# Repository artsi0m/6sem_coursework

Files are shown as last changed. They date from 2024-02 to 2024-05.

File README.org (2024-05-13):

* Курсовой шестого семестра
Программное обеспечение моделирования физических процессов,
протекающих в системе тестирования сервоприводов квадрокоптера на микроконтроллере ATmega328P

** Используемые программы

| Программа             | Что в ней было произведено                                         |
| Altium Designer       | Схема электрическая принципиальная, экспорт модели из кикада в IDF |
| KiCAD 8               | Схема электрическая принципальная, модель печатной платы           |
| Solidworks Simulation | Импорт IDF из Altium, физические симуляции и экспорт в STEP        |
| COMSOL, ANSYS         | Физические симуляции                                               |

** Используемые классы [xe]latex

| Класс | Документ                                                          |
| xesel | Перечень элементов                                                |
| eskdx | Класс взятый за основу класса bsuir-std для пояснительной записки |

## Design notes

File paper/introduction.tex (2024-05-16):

\tableofcontents
\newpage
\begin{center}
\textbf{Перечень условных обозначений, символов и терминов}
\end{center}

ГОСТ — государственный стандарт.

МКЭ – метод конечных элементов.

САПР — системы автоматизированного проектирования.

РЭС — радиоэлектронное средство.

ШИМ — широко импульсная модуляция.

ПП — печатная плата.

\textit{CAE} — \textit{Computer Aided Engineering}, система автоматизации инженерынх расчетов.

\textit{DPDT} — \textit{Double Pole Double Throw}, переключатель два полюса, два направления.

\textit{GPIO} — \textit{ General Purpose Input Output}, система ввода-вывода общего пользования

\textit{OLED} — \textit{Organic light emitted diode}, органический светодиод.

\textit{I2C} — \textit{Inter-Integrated Circuit}, интерфейс микрокнтроллера.

\textit{TDP} — \textit{Thermal Dessipation Power}, рассеиваемая тепловая мощность.

\textit{PCB} — \textit{Printed Circuti Board}, печатная плата.

\newpage

\begin{center}
\textbf{ВВЕДЕНИЕ}
\end{center}

Владение системами автоматизированных инженерных расчетов явлюятся одним из важным навыков современного инженера.

В данной курсовой работе рассмотрены результаты моделирования печатной платы и анализа несколькими системами автоматизированных инженерных расчетов, использующих метод конечных элементов.

Проведен частотный и термический анализ.

Частотный анализ позволяет оценить физические характеристики печатной платы на различных рабочих частотах, что необходимо для обеспечения
стабильной работы устройства в условиях переменных нагрузок и окружающей среды.

Термический анализ, в свою очередь, позволяет выявить и устранить потенциальные проблемы с перегревом компонентов, что является критическим
аспектом для обеспечения долговечности и надежности работы устройства.
Целью курсовой работы является общетехнический анализ устройства,
моделирование его физических процессов, а также анализ полученных результатов.

\newpage

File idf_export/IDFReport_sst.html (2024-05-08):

Altium customize

# IDF File Translation Report

Date: | | 08.05.2024
Time: | | 12:58:33
Elapsed Time: | | 00:00:00
PCB Filename | : | C:\Users\artsi0m\Documents\Bsuir\6sem\coursework_monorepo\altium_sst\Imported sst\sst.PcbDoc
IDF Board Filename | : | C:\Users\artsi0m\Documents\Bsuir\6sem\coursework_monorepo\idf_export\sst.brd
IDF Library Filename | : | C:\Users\artsi0m\Documents\Bsuir\6sem\coursework_monorepo\idf_export\sst.pro

Errors

Back to top

Warnings

Back to top

Save Warnings

Back to top

Save Errors

Back to top

Export Warnings

Back to top

Export Errors

Back to top

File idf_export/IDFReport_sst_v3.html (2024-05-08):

Altium customize

# IDF File Translation Report

Date: | | 08.05.2024
Time: | | 13:01:17
Elapsed Time: | | 00:00:00
PCB Filename | : | C:\Users\artsi0m\Documents\Bsuir\6sem\coursework_monorepo\altium_sst\Imported sst\sst_v3.PcbDoc
IDF Board Filename | : | C:\Users\artsi0m\Documents\Bsuir\6sem\coursework_monorepo\idf_export\sst_v3.brd
IDF Library Filename | : | C:\Users\artsi0m\Documents\Bsuir\6sem\coursework_monorepo\idf_export\sst_v3.pro

Errors

Back to top

Warnings

Back to top

Save Warnings

Back to top

Save Errors

Back to top

Export Warnings

Back to top

Export Errors

Back to top

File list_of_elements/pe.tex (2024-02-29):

%%% Local Variables: 
%%% coding: utf-8
%%% mode: latex
%%% TeX-engine: xetex
%%% End: 
\documentclass{xesel}
\usepackage{polyglossia}
\setdefaultlanguage{russian}
\setotherlanguage{english}
\defaultfontfeatures{Mapping=tex-text}
\setmainfont[AutoFakeSlant=0.25,AutoFakeBold=0.2,Scale=0.85]{opengosta.otf}
\begin{document}
\XeselDesignedBy{Корякин А.Л. }
\XeselCheckedBy{Джанибеков Х.Ш. }
\XeselDocumentNumber{ГУИР.467993.013 ПЭ3}
% Придётся схему переделать ещё раз,
% потому что в Altium элементы могут быть расставлены в другом порядке
\XeselDocumentName{Система тестирования сервоприводов квадрокоптера}
\begin{xesel}
  \XeselEntry{}{}{}{}
  \XeselHeader{Зуммеры}
  \XeselEntry{BUZ1}{Пьезо зуммер с осцилятором\, диаметр 12 мм\,
    шагом  6.6 мм или 7.5 мм}{1}{}
  \XeselEntry{}{}{}{}
  \XeselHeader{Конденсаторы}
  \XeselEntry{C1}{THT 35\,В 100\,мкФ}{1}{}
  \XeselEntry{C2}{THT 16\,В 10\,мкФ}{1}{}
  % Поменял здесь многие компоненты по расположению,
  % они не связаны с оригинальной схемой
  \XeselEntry{C3...С5}{THT 100\,нФ}{3}{}
  \XeselEntry{C6, C7}{THT 22\,пФ}{2}{}
  \XeselEntry{}{}{}{}
  \XeselHeader{Диоды}
  \XeselEntry{D1}{THT 1N5817}{1}{ Диод Шоттки}
  \XeselEntry{D2}{THT LM385Z-2.5\, TO-92}{1}{}
  \XeselEntry{D3}{THT BZX79-C5V1}{1}{ Диод Зенера}
  \XeselEntry{}{}{}{}
  \XeselHeader{Микросхемы}
  \XeselEntry{IC1}{TO220 7805}{1}{}
  \XeselEntry{IC2}{ATmega328P}{1}{}
  \XeselEntry{}{}{}{}
  \XeselHeader{Разъёмы штырьевые и блоки клемные}
  \XeselEntry{K1, K2}{THT Разъём штырьевой\, двухрядный\,
    12 позиционный\, с шагом 2.54 мм}{2}{}
  \XeselEntry{K3}{THT Разъём штырьевой\, двухрядный\,
    6 позиционный\, с шагом 2.54 мм}{1}{}
  \XeselEntry{K4}{THT Разъём штырьевой\,
    4 позиционный\, с шагом 2.54 мм}{1}{}
  \XeselEntry{K5}{THT Разъём питания коаксильный}{1}{}
  \XeselEntry{}{}{}{}
  \XeselHeader{Светодиоды}
  \XeselEntry{LED1}{Cветодиод\, 3мм\, красный }{}{}
  \XeselEntry{}{}{}{}
  \XeselHeader{Потенциометры}
  \XeselEntry{P1...P4}{THT Потенциометр\, 10 кОм\, 0.25 Вт}{4}{}
  \XeselEntry{}{}{}{}
  \XeselHeader{Резисторы}
  \XeselEntry{R1, R2}{THT Резистор\, 1 кОм\, 0.25 Вт}{2}{}
  \XeselEntry{R3...R9}{THT Резистор\, 10 кОм\, 0.25 Вт}{7}{}
  \XeselEntry{R10}{THT Резистор\, 22 Ом\, 0.25 Вт}{1}{}
  \XeselEntry{}{}{}{}
  \XeselHeader{Переключатели ползунковые}
  \XeselEntry{S1}{Переключатель ползунковый  DPDT MFS201N-16-Z}{1}{}
  \XeselEntry{S2}{Переключатель ползунковый SPDT OS102011MA1}{1}{}
  \XeselEntry{}{}{}{}
  \XeselHeader{Транзисторы}
  \XeselEntry{T1}{Транзистор 2N7000\, в корпусе TO-92}{1}{}
  \XeselEntry{}{}{}{}
  \XeselHeader{Резонаторы кварцевые}
  \XeselEntry{X1}{HC-49S 16Мгц}{1}{}
  \XeselEntry{}{}{}{}
\end{xesel}
\end{document}

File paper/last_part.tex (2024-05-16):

\begin{center}
\textbf{Заключение}
\end{center}

В результате выполнения курсового проекта проведен общетехнический
анализ проектируемого устройства, который включает: анализ исходных данных, описание принципа работы анализируемого устройства, анализ электрической принципиальной схемы устройства, определение параметров воздействующих дестабилизирующих факторов и протекающих физических процес-
лсов для последующего моделирования.

Проведено моделирование физических процессов, воздействующих на
устройство, а именно: обоснование выбора прикладного программного обеспечения для моделирования физических процессов, разработан план моделирования физических процессов, разработана методика построения трехмерной модели исследуемого устройства, проведено моделирование механических
процессов, протекающих в электронном модуле и устройстве в целом, и проведено моделирование тепловых процессов, протекающих в электронном модуле и устройстве в целом.
Основываясь на вышеперечисленном, был проведен анализ полученных
результатов, а также дана краткая оценка.

Таким образом была предпринята попытка реализовать все поставленные цели и задачи на курсовой проект. Однако с уверенностью можно заключить, что эта попытка не была удачной. Большую роль сыграли проблемы с экспортом модели трехмерной модели, случившиеся в результате перехода на другую систему автоматизированного проектирования печатной платы.

Остается только сделать выводы и не допускать ошибок, подобных допущенным при выполнении данного курсового проекта.
  \newpage

% \bibligoraphystyle{5sem}
% \renewcommand{\bibsection}{{Cписок использованных источников}}
\renewcommand{\refname}{\textbf{Cписок использованных источников}}
\DeclareFieldFormat{url}{Режим доступа\addcolon\space\url{#1}}
\DeclareFieldFormat{title}{{#1}}
\DeclareFieldFormat{labelnumberwidth}{[{#1}]\adddot  }
\printbibliography

\newpage
\begin{center}
\textbf{Приложение А}\\
\textbf{Обязательное}\\
\textbf{Параметры компонентов}
\end{center}

Техническое описание ПП:
\begin{enumerate}[label={\arabic*.}]
\item Соотношение сторон 1:1.
\item Габариты ПП 75 на 75 мм.
\item Толщина ПП 0,8 мм.
\end{enumerate}

Данные необходимые для тепловго анализа:
\begin{enumerate}[label={\arabic*.}]
\item Температура окружающей среды 315 К.
\item Коэффициент конвекции — 25 Вт/К * м².
\end{enumerate}

\newpage

\begin{center}
\textbf{Приложение Б}\\
\textbf{Обязательное}\\
\textbf{Отчет о проверке на заимствования в системе «Антиплагиат»}

\begin{figure}[H]
  \centering
  
  \caption{Результат проверки на заимстования в системе «Антиплагиат»}
\end{figure}
\end{center}

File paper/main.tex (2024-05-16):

%%% Local Variables: 
%%% coding: utf-8
%%% mode: latex
%%% TeX-engine: xetex
%%% End:

% main.tex файл который компилируется и подключает за собой остальный
% файлы с содержимым через input
% При этом согласно моей же логике преамбула должна отстаться здесь.

% Используем опцию emptystyle т.к. bsuir-std расширяет eskdxtext,
% который без этой опции сделает рамку для чертежа даже на документе
% с просто текстом.
\documentclass[a4paper,emptystyle]{bsuir-std}

\usepackage[sorting=none,backend=biber]{biblatex}
% библиогорафия в last
\usepackage{url}

\usepackage{float}

\addbibresource{Karakin6semCoursework.bib}

\begin{document}

% Путь к месту где картинки лежат
\graphicspath{ {..} }

%%% Титульник
\input{title}

%%% Введение.
\input{introduction}

%%% Первая глава
%%% Общетехнический анализ проектируемо устройства

%%%% Анализ исходных данных
\input{part_1_1}

%%%% Описание принципа работы анализируемого устройства
\input{part_1_2}

%%%% Анализ электрической принципиальной схемы устройства
\input{part_1_3}

%%%% Определение параметров
%%%% воздействующих дестабилизирующих факторов и
%%%% протекающих физических процессов

% Приплести сюда ГОСТ на устройство
\input{part_1_4}

%%% Вторая глава по разделам

\input{part_2_1}

\input{part_2_2}

\input{part_2_3}

\input{part_2_4}

\input{part_2_5}

\input{part_3_1}

\input{part_3_2}

\input{last_part}

\end{document}

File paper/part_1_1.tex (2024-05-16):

\section{ОБЩЕТЕХНИЧЕСКИЙ АНАЛИЗ ПРОЕКТИРУЕМОГО УСТРОЙСТВА}
\subsection{Анализ исходных данных}

В курсовой работе рассматривается система тестирования сервоприводов квадрокоптера.
Назначение этой системы — тестирование отдельных частей квадрокоптера,
таких как сервоприводы,
блок управления скоростью или контроллер полёта ~\cite{Elector521}.
Говоря кратко — это тестовый стенд.

Тестовый стенд выполнен в виде платы,
на которую с помощью монтажа в отверстия помещаются компоненты.
Вероятно, что такой способ мантажа выбран для того,
чтобы облегчить сборку данной схемы,
установку и смену тестируемых компонентов
или незначительного изменения схемы,
необходимого для взаиомодействия с определенными компонентами.

Поскольку в курсовой работе будет производиться расчёт тепловых
режимов будет также важно учитывать климатические факторы внешней
среды, то какие условия эксплутации при этом должны быть соблюдены
регламентирует соответсвующий стандарт — ГОСТ 15150-69
~\cite{GOST-15150-69}.

Настоящий стандарт должен применяться при проектировании изделий.  В
частности, он должен применяться при составлении технических заданий
на разработку или модернизацию изделий, а также при разработке
государственных стандартов и технических условий, устанавливающих
требования в части воздействия климатических факторов внешней среды
для группы изделий, а при отсуствии указанных групповых документов —
для отдельных видов изделий ~\cite{GOST-15150-69}.

Для конкретных типов или групп изделий виды воздействующих
климатических факторов и их номинальные значения устанавливаются в
зависимости от условий эксплуатации изделий в соответвующих
технических заданих, стандартах и технических условиях ~\cite{GOST-15150-69}.

Так как в данном случае тестовый стенд используется для того,
чтобы тестировать отдельные компоненты и их взаимодейтевие,
то логично предположить,
что в течении всего жизненного цикла изделия,
оно не будет покидать пределов лаборатории,
в которой будут проводиться испытания,
осуществляемые на данном тестовом стенде.
Основываясь на этом, можно говорить,
что климатические условия эксплуатации данного устройства соответвуют категории УХЛ 4.2 ГОСТ 15150-69.

Характеристика данной категории следующая:\\
Для эксплуатации в помещниях (объемах) с искуственно регулируемыми
климатическими условиями, например в закрытых отапливаемых или
охлаждаемых и вентелируемых производственных и других, в том числе
хорошо вентилиуруемых подземных помещниях (отсуствие воздействия
прямого соленчного излучения, атмосферных осадков, ветра, песка и пыли
наружного воздуха; отсутвие или существенное уменьшение воздействия
рассеяного солнечного излучения и конденсации влаги). Для эксплуатации
в лабораторных, капитальных и других подобного типа помещениях ~\cite{GOST-15150-69}.

Соответсвие условий работы тестового стенда определенной категории,
указанной в ГОСТ, важно по той причине,
что расчеты внешних тепловых воздействией оказываемых на данную РЭС будут производиться с использованием исходных данных о температуре,
указанных в конкретной категории ГОСТ.

Также исходя из правил установленных ГОСТ ЕСКД устройству назначен код из классификатора.
При этом использовался общероссийский классификатор изделий и конструкторских документов ОК 012-93.
Этот код ГУИР 467993.013. Здесь ГУИР это код предприятия, а 013 порядковый регистрационный номер,
соответствующий номеру студента в списке группы.
Остальные шесть цифр обозначают то чем именно является устройство.
Первые две цифры — 46 — класс устройства, последующие четыре цифры,
это подкласс, группа, подгруппа и вид устройства.

Класс устройcтва 46 обозначает средства радиоэлектронного управления, связи, навигации и вычислительной техники.
Это довольно обширный класс, под который подпадает большинство возможных устройств,
которые могут быть разработаны инженером по радиоэлектронике.

Подкласс и группа относит устройство к комплектам монтажным и эксплуатационным,
имитаторам,
средствам контрольно-испытательным.

Подгруппа и вид устройства обозначают устройство как электронное средство контрольно-испытательных составных частей функциональных.

Исследование методом конечных элементов
позволяет сократить число изготавливаемых прототипов и проводимых эксперементов с ними,
при конструировании, разработке и контроле за устройством или процессом.
Это не означает, что компании или исследовательские институты,
применяющие исследования методом конечных элементов экономят деньги применяя МКЭ.
Однако за ту же цену они получают больше разработок,
что позволяет им иметь преимущество при конкуренции.
По этой причине может быть смысл в том,
чтобы увеличить ресурсы затарчиваемые на исследования и разработку для МКЭ.
Когда МКЭ модель создаётся и становится полезной она может привнести
понимание о небходимых для совершенствования устройства изменений,
которое сложно получить пользуясь одной только интуицией~\cite{MULTIPHYSICS-CYCLOPEDIA-FEM}.

Обосновав важность моделирования,
можно перечислить программы используемые для его осущствления в этом курсовом.
Это система автоматизированного проектирования \textit{SOLIDWORKS}.
Одно из дополнений (\textit{Add-Ins}) используемое для симцуляций в этой программе — \textit{SOLIDWORKS Simulation}.
Также использовались такие программы как \textit{COMSOL Multiphysics} и \textit{Ansys Workbench}.

\textit{COMSOL Multiphysics} и \textit{Ansys Workbench} это программы относящиеся к классу \textit{CAE} программ.
Аббревитура \textit{CAE} рассшифровывается как \textit{computer aided engineering},
переводится как система автоматизации инженерных расчетов и анализа и обозначет целый класс программ,
предназначенных для инженерных рассчетов.

При этом в русском языке существует общеупотребимый термин САПР — системы автоматизированного проектирования,
но он настолько всеобъемлющ, что включает в себя как программы для инженерных рассчетов используемые в данной работе,
так и просто программы для создания чертежей и трёхмерных моделей детали или сборки.

Если же уточнять, а не обобщать, то можно сказать,
что и \textit{COMSOL Multiphysics}, и \textit{SOLIDWORKS Simulation},  и \textit{ANSYS Workbench},
являются программным обеспечением для вычислений методом конечных элементов.

Проведение анализа сразу в нескольких \textit{CAE}-программах позволяет сравнить результаты и проверить адекватность полученных данных.

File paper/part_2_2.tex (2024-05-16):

\subsection{Разработка плана моделирования физических процессов}

Под моделированием можно понимать метод исследования, оценок характеристик сложных сечений используемый для принятия решения в различных сферах инженерной деятельности.

Под моделью следует понимать объект заместитель, который в определенных условиях может заменить объект оригинала воспроизводя интересующее исследователя свойство оригинала. Чем более подробное описание модели требуется, тем более длительным и затратным окажется вычислительный
процесс.

Основными целями моделирования является: прогноз (главная цель моделирования), оптимизация и анализ чувствительности.

Следовательно, план моделирование физических процессов выглядит так:
\begin{enumerate}[label={\arabic*.}]
\item Построение нескольких варинтов компоновок исследоваемого тестового стенда.
\item Экспорт получившихся печатных плат в виде трёхмерных моделий пригодных для трёхмерного параметрического моделирования и расчетов методом конечных элементов.
\item Проведение инженерных анализов с использованием различных CAE программ.
\item Сравнение результатов анализиа, полученных из программ.
\item Определние адекватности полученных результатов.  
\end{enumerate}

В случае получения неадекватных результатов моделирование должно быть повторено с первого пункта.

Из этого следует что для более детального анализа необходимо
смоделировать различные варианты компоновки тестового стенда, а также
смоделировать и проанализировать, для каждого варианта исполнения,
результаты физических процессов. Моделирование будет проводится до тех
пор, пока не будут получены адекватные результаты.

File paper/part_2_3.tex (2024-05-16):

\subsection{Методика построения трехмерной модели исследуемого устройства}

Создание модели печатной платы было начато в САПР \textit{Altium Designer}.
В нём была создана библиотека УГО принципиальная схема устройства.
Затем, по логике создания моделей в САПР печатных плат подобных \textit{Altium Designer} должны были быть созданы библиотеки посадочных мест, соедиение их с УГО размещенных на принципиальной схеме.
После чего надо было бы разнести посадочные места на печатной плате и произвести трассировку.

Однако я поступил не так.
Из-за своего изначального предпочтения к использовонию программ с открытым исходным кодом было принято решение использовать САПР печатных плат \textit{KiCAD}.

В тот момент процедура создания печатных плат в \textit{KiCAD}, казалась проще, чем в \textit{Alitum Designer}. Всё дело в том, что у \textit{KiCAD} существует своя библиотека посадочных мест с трёхмерными моделями соотвествующих компонентов в формате \textit{STEP} и \textit{WRL}. Также на \textit{Github} была найдена готовая библиотека УГО соотвествующая ГОСТ.
В \textit{KiCAD} нет предустановленного встроенного автотрассировщика и потому разводка платы производилась вручную,
несмотря на то что можно было бы установить автотрассировщик \textit{freerouting}.

На этом этапе казалось, что выбор \textit{KiCAD} в качестве САПР печатных плат всё только упрощает, поскольку теперь было достаточно:
\begin{enumerate}[label={\arabic*.}]
\item Создать схему электрическую принципиальную, используя готовую библиотеку УГО.
\item На схеме установить соотвествие между УГО и посадочными местами, у которых есть свои трёхмерные модели.
\item Импортировать получившиеся связи непосредственно в документ, в котором осуществляется разводка печатной платы.
\item Рапределить компоненты в группы и провести дорожки наиболее эффективных способом.
\end{enumerate}

Это и было сделано. На тот момент подозрений о том, что это приведёт к каким-либо проблемам не было.

\begin{figure}[H]
  \centering
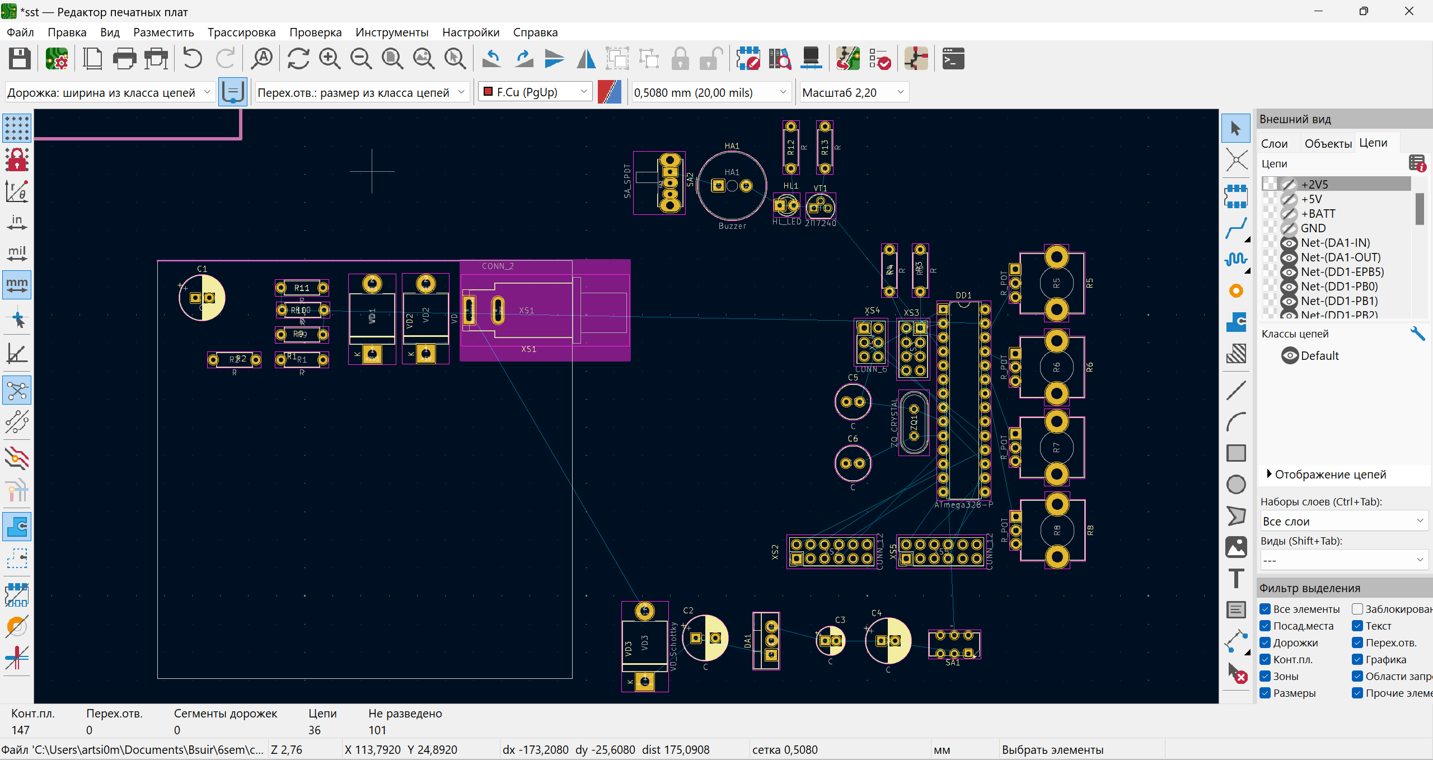
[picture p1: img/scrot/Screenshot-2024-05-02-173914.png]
  
 \caption{Скриншот окна САПР \textit{KiCAD} в котором скрыты цепи относящиеся к питанию и компоненты распределены по группам.}
\end{figure}

Была произведена разводка первой печатной платы:
сначала скрыты цепи связанные с питанием, затем компоненты были объеденены в группы, после чего расставлены по контуру печатной платы и соедены дорожками.

Чтобы заново не производить разводку, а если быть предельно точным,
соединение компонентов было сделать две последующие компоновки печатной платы следующим способом:

В случае второй компоновки просто заменить расположение некоторых посадочных мест, таким образом, чтобы они оказались на другой стороне печатной платы, но подали в нужные отверстия печатной платы. В основном это относилось к резисторам, которые в последствии были использованы, как элементы выделяющие тепло в термическом анализе.

В случае третьей платы были заменены некоторые посадочные места, на минитюаризированные аналоги, в описании которых при этом значился тот же самый шаг (\textit{pitch}) между отверстиями.

\begin{figure}[H]
  \centering
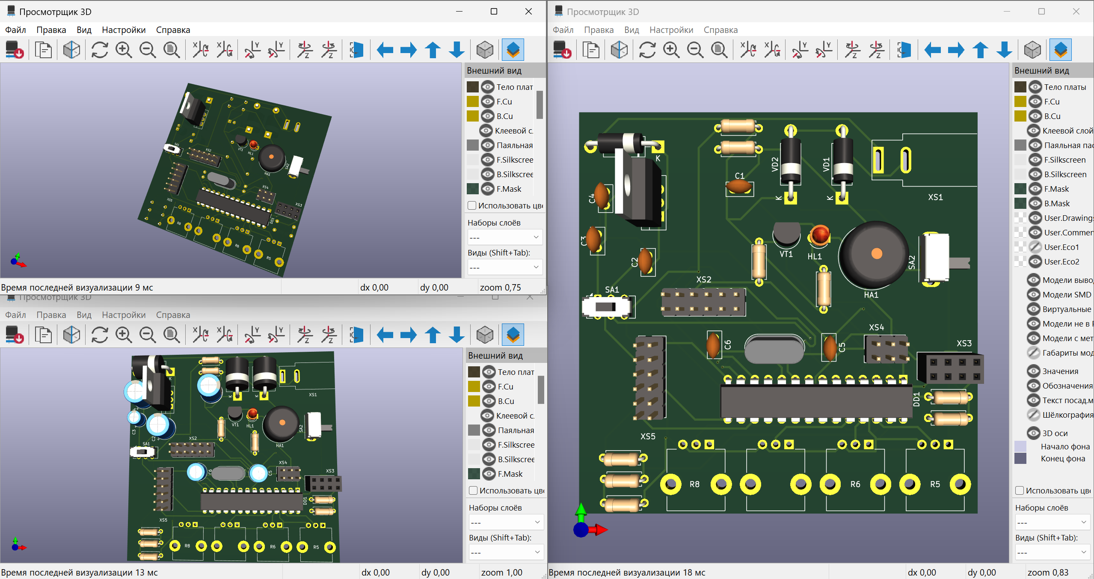
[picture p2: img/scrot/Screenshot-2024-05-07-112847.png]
  
 \caption{Скриншот окон просмотрщика трёхмерных моделей САПР \textit{KiCAD}}
\end{figure}

Полученные варианты печатной платы необходимо экспортировать в \textit{SOLIDWORKS} для проведения дальньшей симуляции. И вот здесь возникли проблемы с получившийся моделью.

\begin{figure}[H]
  \centering
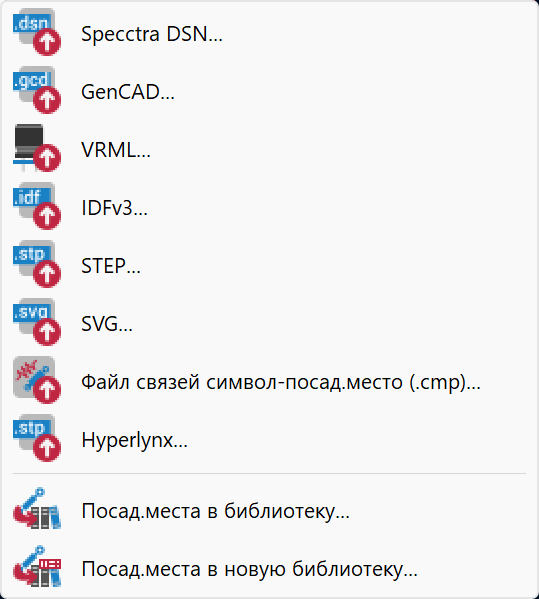
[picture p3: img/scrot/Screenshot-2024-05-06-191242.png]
  
  \caption{Скриншот меню экспорта печатной платы в САПР \textit{KiCAD} }
\end{figure}

В первую очередь была осуществлена попытка экспортировать печатную плату из \textit{KiCAD} в формате \textit{STEP}. Конечно же модель успешно экспортировалась. Проблема была в другом: полученная модель была излишне подробна. Расчет такой модели в \textit{SOLIDWORKS Simulation} мог занимать по пять минут для частотного анализа, но, что более критично, часто приводил к зависанию или падению \textit{SOLIDWORKS}.

Для того, чтобы решить эту проблему было предпринята попытка экспортировать в формате \textit{IDFv3}. Это решение было принято из-за того, что подразумевалось,
что при импорте полученного \textit{IDF} файла в \textit{SOLIDWORKS} будет автоматически использовано дополнение \textit{Circuit WORKS}, которое в случае импорта из \textit{Аltium Designer} упрощало модель таким образом, что вместо точных трехмерных моделей компонентов получались схожие, но значительно упрощенные трёхмерные геометрические фигуры.

\begin{figure}[H]
  \centering
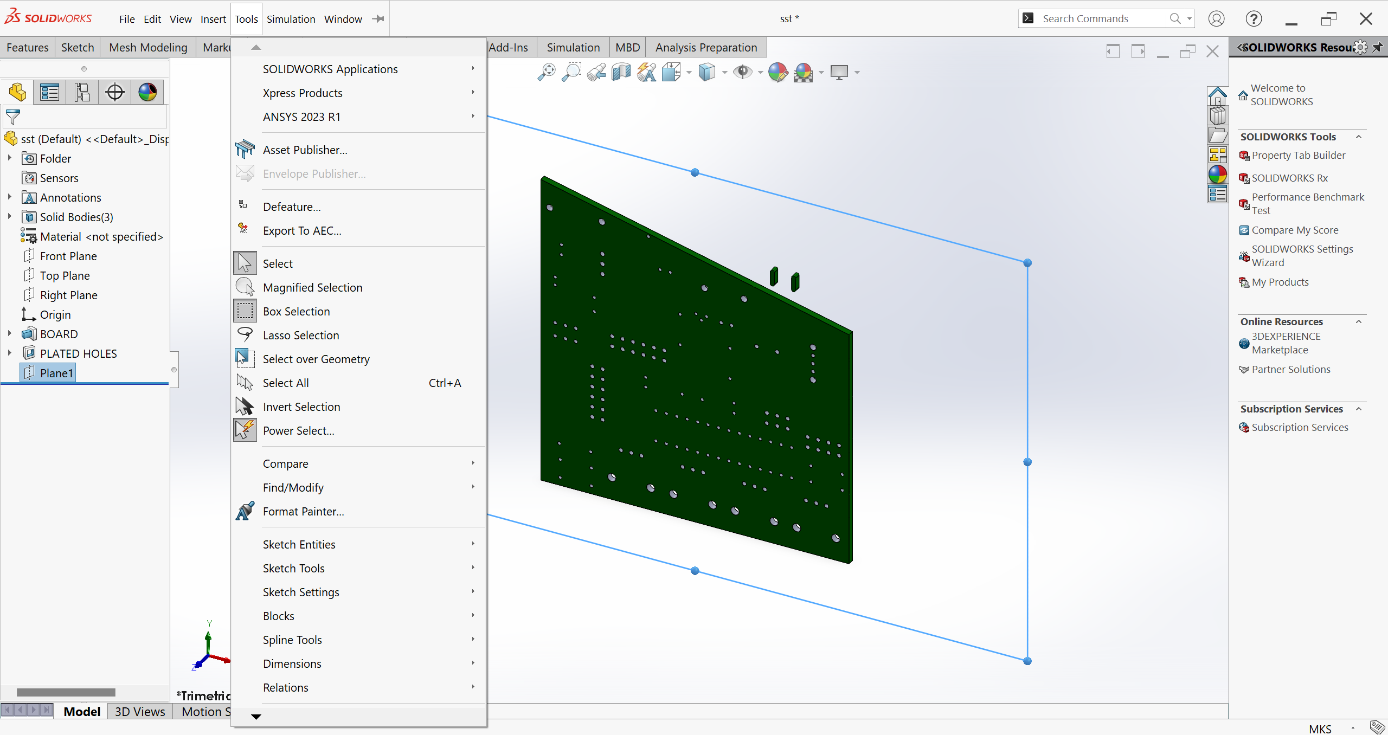
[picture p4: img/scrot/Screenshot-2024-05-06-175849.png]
  
  \caption{Скриншот импортированного IDF печатной платы в САПР \textit{SOLIDWORKS}}
\end{figure}

Однако и эта попытка кончилась провалом. Импортированная плата не имела вообще никаких компонентов и была упрощена черезмерно.

Было понятно, что нужно будет переделывать в \textit{Altium Designer} какую-то часть проекта, чтобы получить полноценную трёхмерную модель печатной платы.

Однако совсем не хотелось терять проделанную работу, поэтому было установлено расширение для \textit{Altium Designer} под названием \textit{KiCAD Importer}, которое предоставляло мастер импорта проектов из \textit{KiCAD}.

\begin{figure}[H]
  \centering
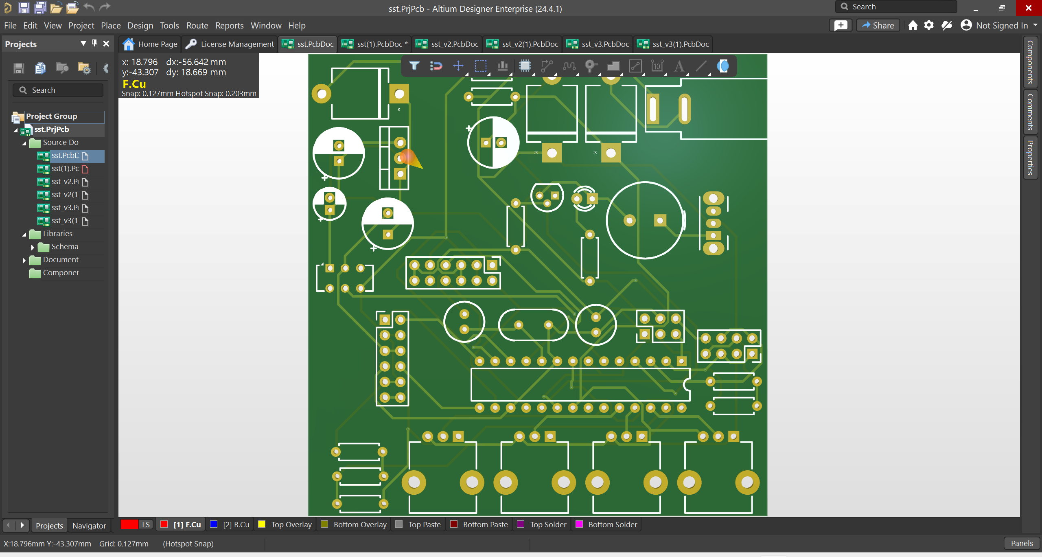
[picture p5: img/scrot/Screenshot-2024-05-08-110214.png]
  
  \caption{Скриншот трёхмерной модели имопрированной из \textit{KiCAD} печатной платы в \textit{Altium Designer}}

\end{figure}

В результате импорта в проекте \textit{Altium} появились соотвественно три документа печатных плат.

После этого модели были экспортированы из \textit{Altium} в формате \textit{IDF}. Затем был осуществлен импорт этих моделей в \textit{SOLIDWORKS}. В отличие от моделей получившихся при предыдущей попытке экспорта теперь была сохранена геометрия платы и остались контуры (\textit{Sketch}) от элементов расположенных на ней. В последствии инструментом \textit{Extrude} на вкладке \textit{Analysis Prepartion} было осуществлено выдавливание фигур, схожих по объёму с трехмерным моделями печатных плат.

\begin{figure}[H]
  \centering
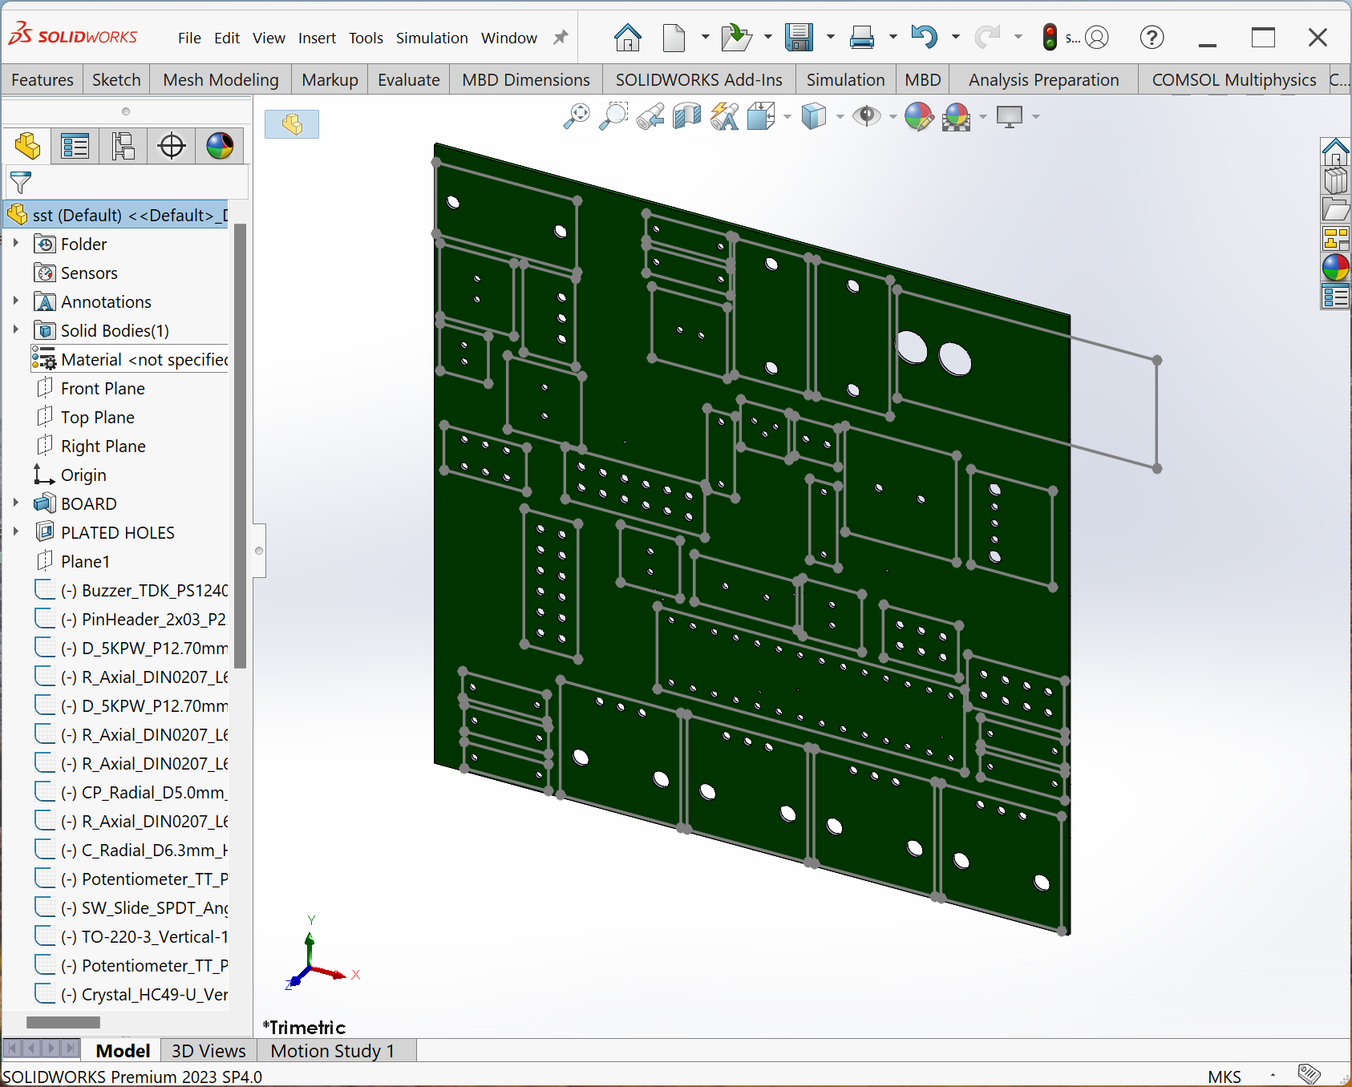
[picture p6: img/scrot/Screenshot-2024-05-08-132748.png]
  
  \caption{Скриншот только импортированной в \textit{SOLIDWORKS} печатной платы в формате IDF из \textit{Altium Designer}. Видны контуры посадочных мест.}

\end{figure}

Изначально зная о том, сколько работы будет потрачено, на всего лишь, экспорт трёхмерной модели печатной платы я бы не стал использовать для этого САПР \textit{KiCAD} даже несмотря на возможное удобство в непоредственно проектировании.

Из этого можно сделать вывод, что при выполнение подобных проектов, при выбьоре определенного САПР стоит руководствоваться совместимостью его с другими программами.
Или хотя бы заренее проверять на каком-то миниатюрном проекте-приемере возможность перенесения модели из одной программы в другую.

Что же касается непосредственно проектирвония, то, возможно, было опрометчиво отказываться от использования монтажных отверстий в плате.

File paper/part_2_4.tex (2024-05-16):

\subsection{Моделирование механических процессов, проетекающих в электронном модуле и устройстве в целом}

Результаты частотного анализа в \textit{SOLIDWORKS Simulation} первого варианта компоновки ПП представлены на рисунке 8.

\begin{figure}[H]
  \centering
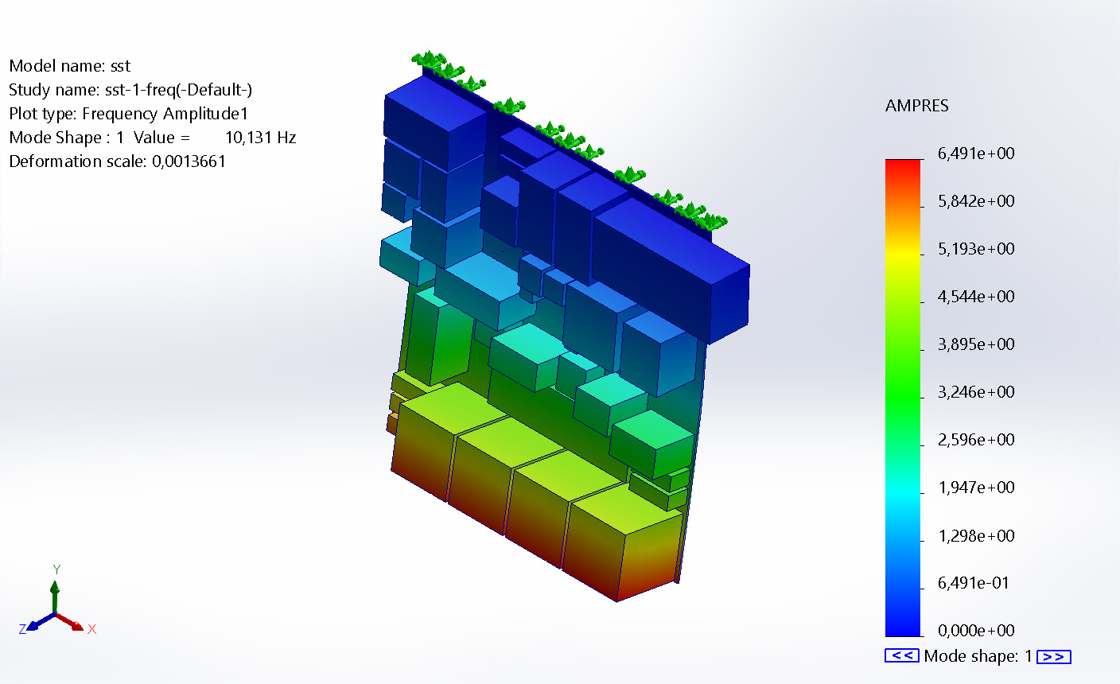
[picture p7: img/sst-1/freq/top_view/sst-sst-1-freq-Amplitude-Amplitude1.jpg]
  
  \caption{Результаты частотного анализа в \textit{SOLIDWORKS SIMULATION} первого варианта компоновки ПП.}
\end{figure}

На рисунке 9 представлены результаты частотного анализа в \textit{SOLIDWORKS Simulation} второго варианта компоновки печатной платы.

\begin{figure}[H]
  \centering
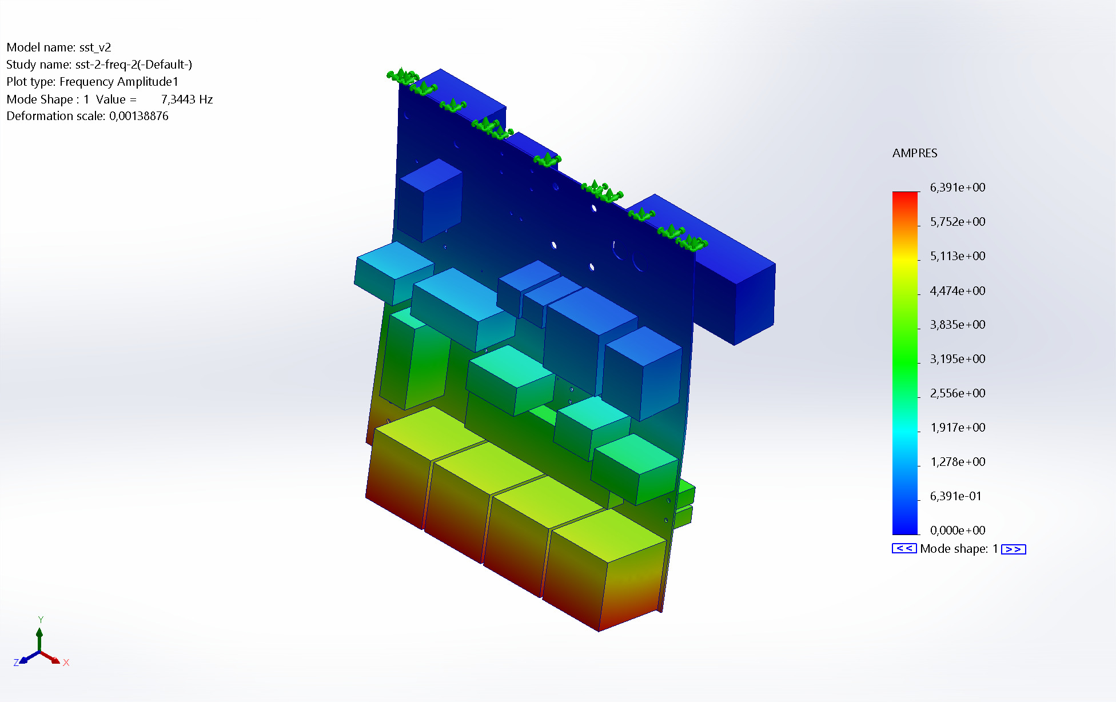
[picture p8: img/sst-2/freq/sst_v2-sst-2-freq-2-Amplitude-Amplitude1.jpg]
  
  \caption{Результаты частотного анализа в \textit{SOLIDWORKS SIMULATION} второго варианта компоновки ПП.}

\end{figure}

На рисунке 10 представлены результаты частотного анализа в
\textit{SOLIDWORKS Simulation} третьего варианта компоновки печатной платы.

\begin{figure}[H]
  \centering
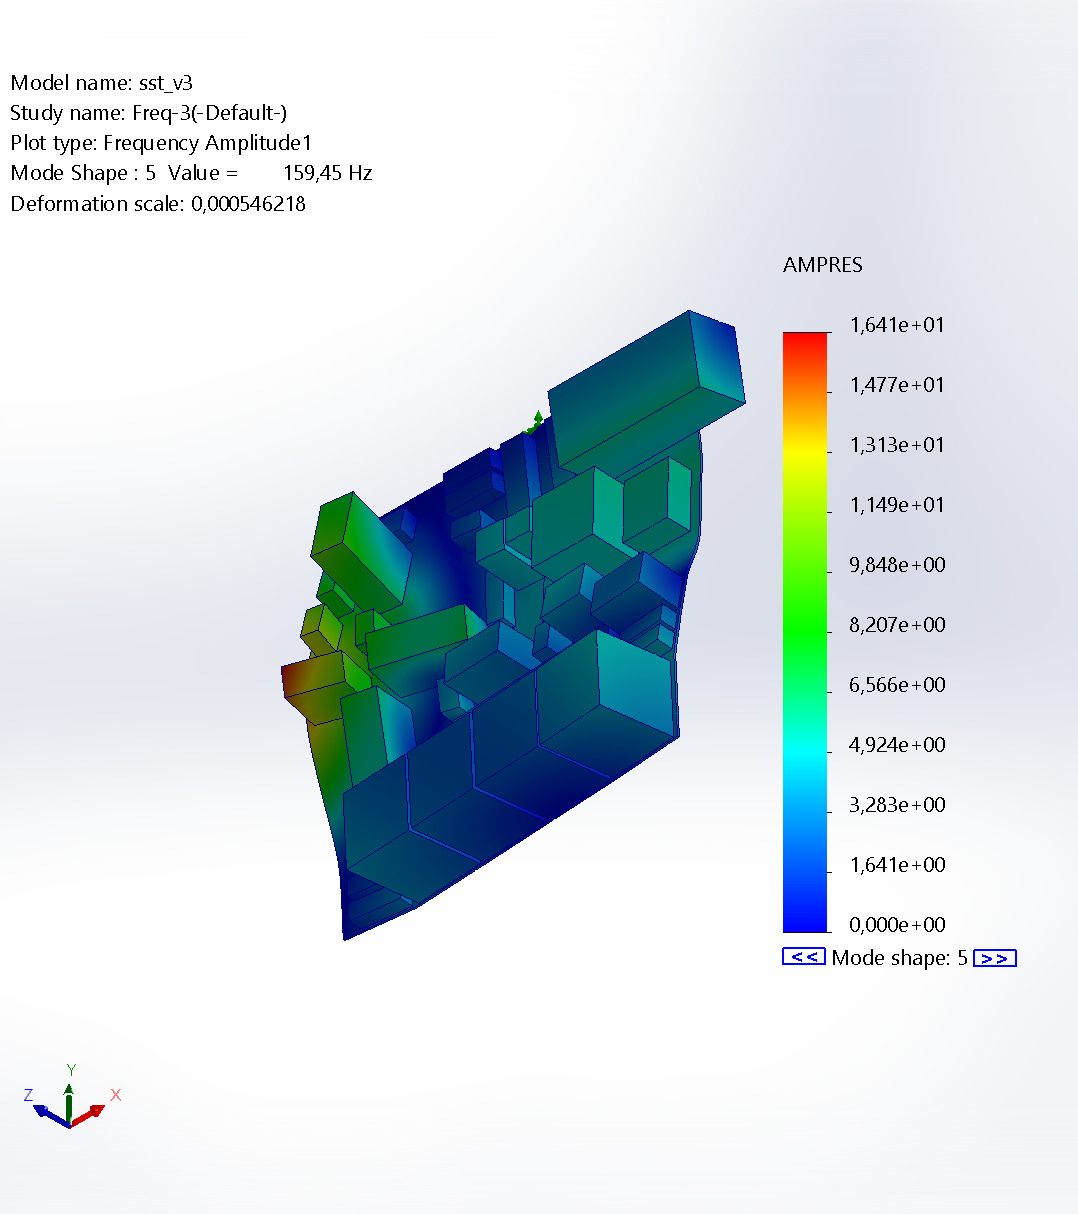
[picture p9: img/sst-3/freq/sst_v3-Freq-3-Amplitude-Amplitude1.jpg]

\caption{Результаты частотного анализа в \textit{SOLIDWORKS Simulation} третьего варианта компоновки ПП.}
\end{figure}

На рисунке 11 представлены результаты частотного анализа в
\textit{COMSOL Multiphysics} первого варианта компоновки печатной платы.

\begin{figure}[H]
  \centering
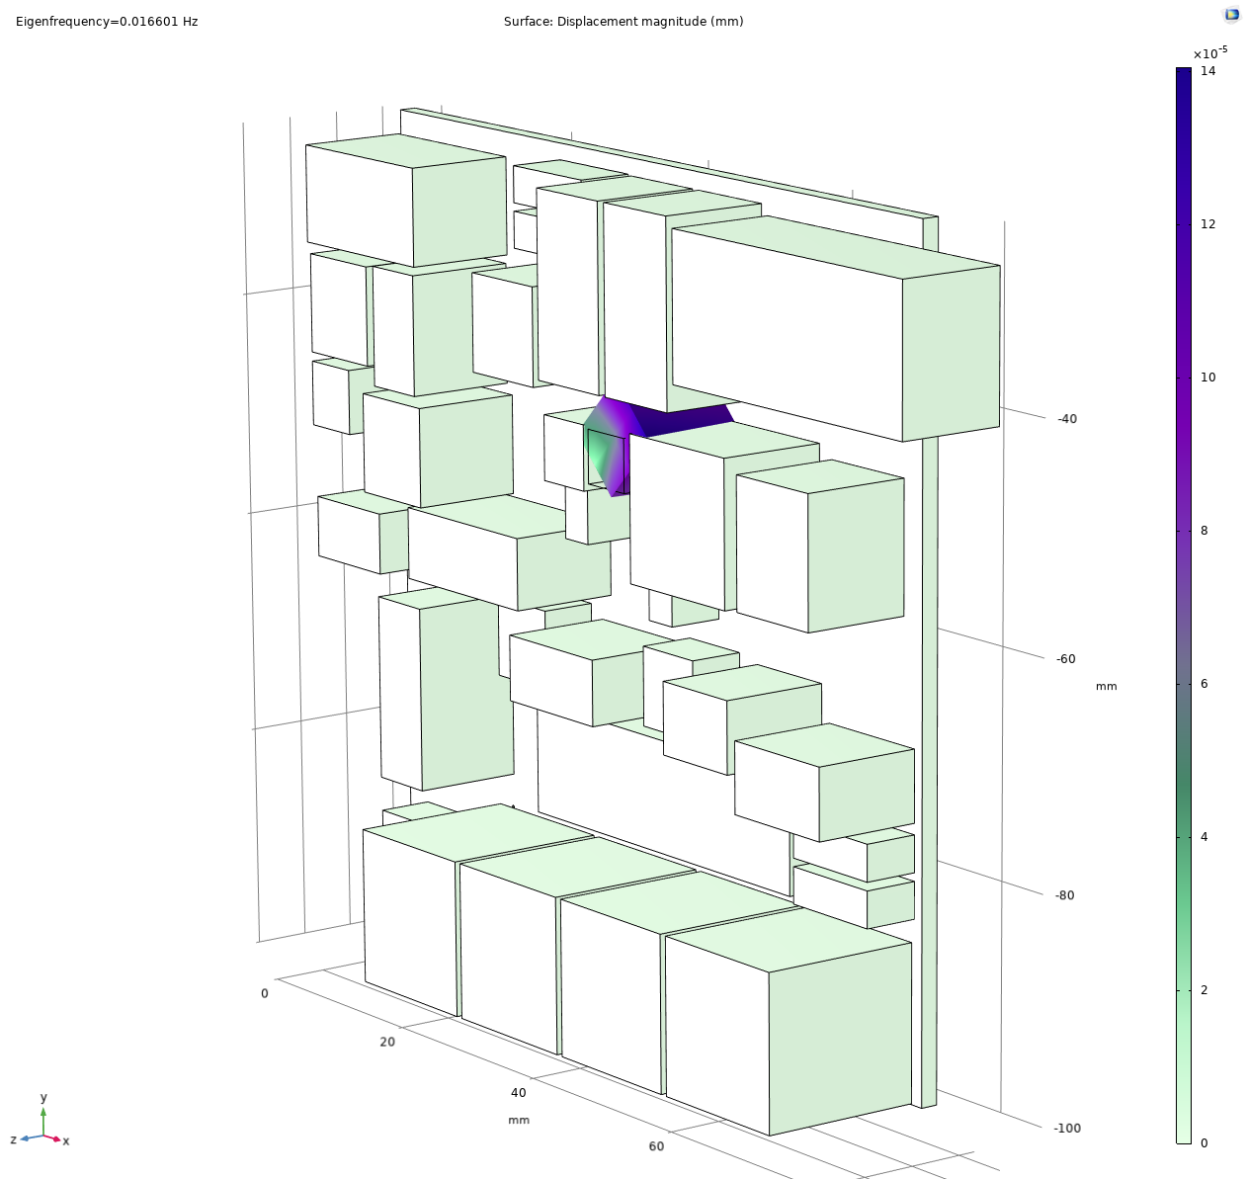
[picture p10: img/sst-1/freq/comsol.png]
  
  \caption{Результаты частотного анализа в \textit{COMSOL Multiphysics} первого варианта компоновки}
\end{figure}

На рисунке 12 представлены результаты частотного анализа в \textit{COMSOL Multiphysics} второго вараинта компоновки печатной платы.

\begin{figure}[H]
  \centering
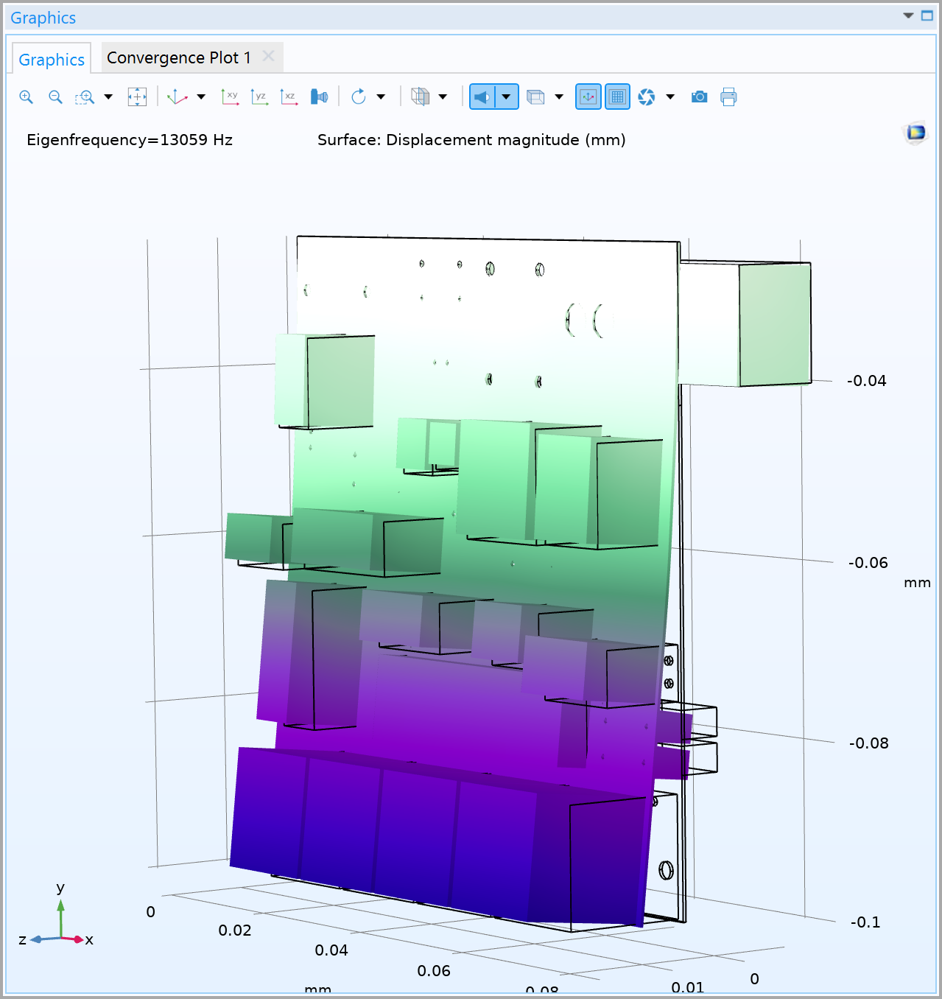
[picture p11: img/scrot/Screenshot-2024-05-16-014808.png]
  
  \caption{Результаты частотного анализа в \textit{COMSOL Multiphysics}
    второго варианта компоновки}
\end{figure}

На рисунке 13 представлены результаты частотного анализа в \textit{COMSOL Multiphysics} третьего варианта компоновки печатной платы.

\begin{figure}[H]
  \centering
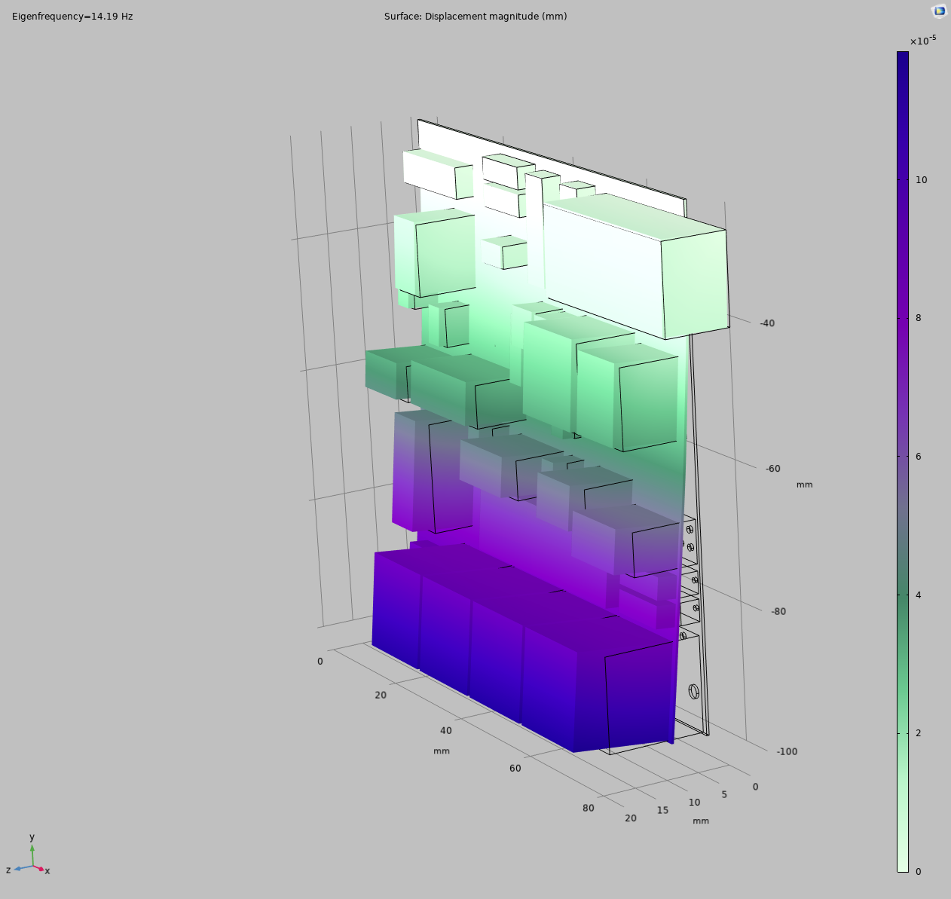
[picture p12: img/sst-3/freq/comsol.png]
  
  \caption{Результаты частотного анализа в \textit{COMSOL Multiphysics}
    третьего варианта компоновки}
\end{figure}

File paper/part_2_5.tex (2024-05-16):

\subsection{Моделирование тепловых процессов, протекающих в электронном модуле и устройстве в целом}

Результаты теплового анализа для первого варианта компоновки ПП
в \textit{SOLIDWORKS Simulation} представлены на рисунке 14.

\begin{figure}[H]
  \centering
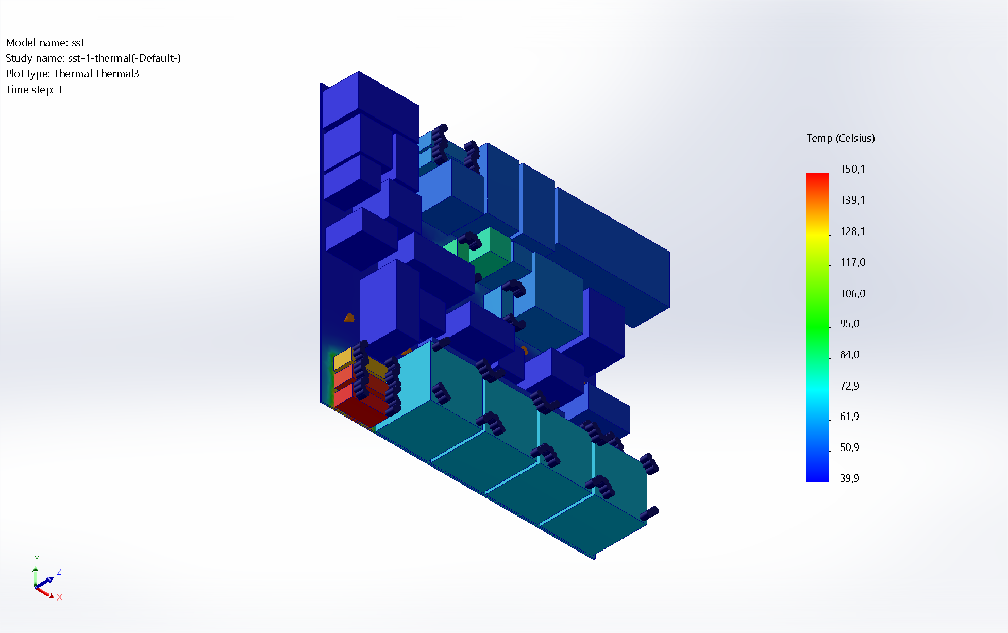
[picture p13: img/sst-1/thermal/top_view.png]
  
  \caption{Результаты теплового анализа в \textit{SOLIDWORKS Simulation}
    для первого варианта компоновки}
\end{figure}

Результаты теплового анализа для второго варианта компоновки ПП в
\textit{SOLIDWORKS Simulation} представлены на рисунке 15.

\begin{figure}[H]
  \centering
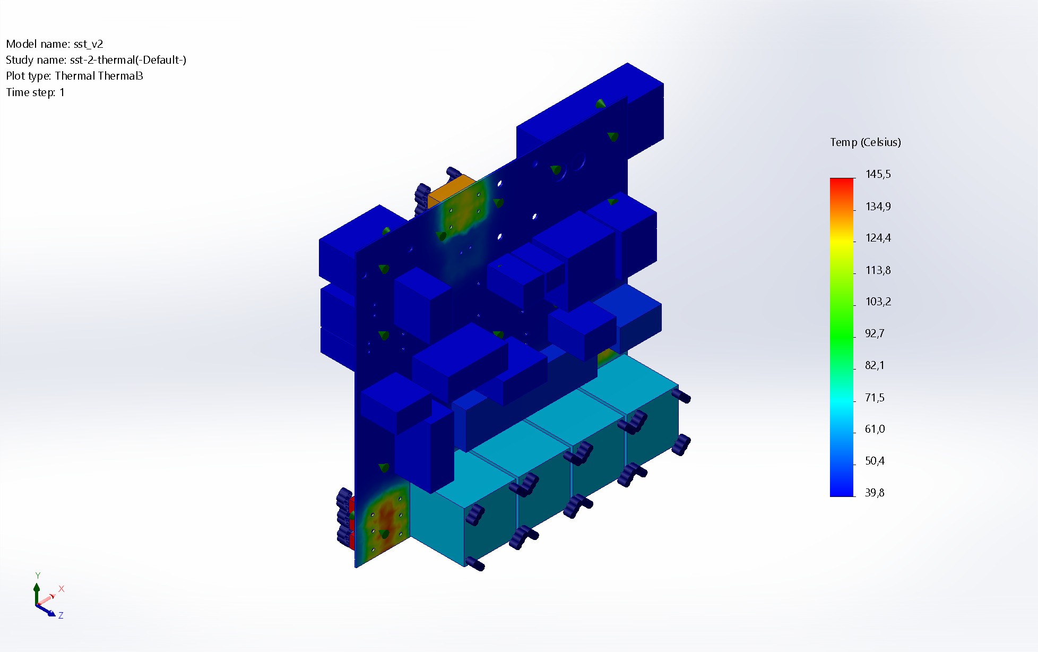
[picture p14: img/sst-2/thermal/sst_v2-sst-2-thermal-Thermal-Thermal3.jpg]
  
  \caption{Результаты теплового аналиаза в \textit{SOLIDWORKS Simulation}
    для второго варианта компновки}
\end{figure}

Результаты теплового анализа для третьего варианта компоновки ПП в
\textit{SOLIDWORKS Simulation} представлены на рисунке 16.
\begin{figure}[H]
  \centering
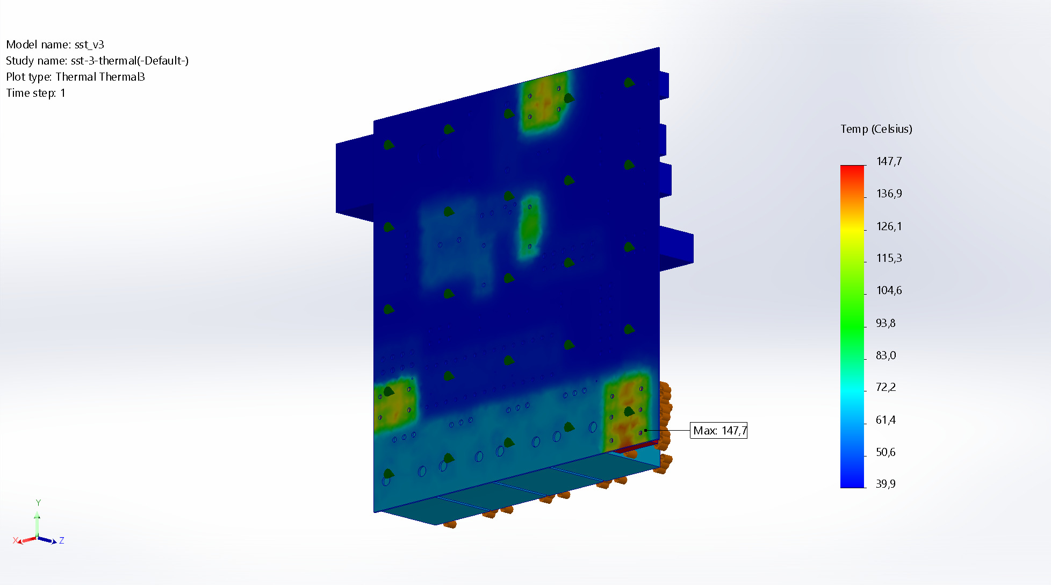
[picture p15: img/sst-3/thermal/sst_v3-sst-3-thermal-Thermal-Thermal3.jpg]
  
  \caption{Результаты теплового аналиаза в \textit{SOLIDWORKS Simulation}
    для второго варианта компновки}
\end{figure}

Результаты тепловго анализа для первого варианта компоновки ПП в
\textit{COMSOL Multiphysics} представлены на рисунке 17.
\begin{figure}[H]
  \centering
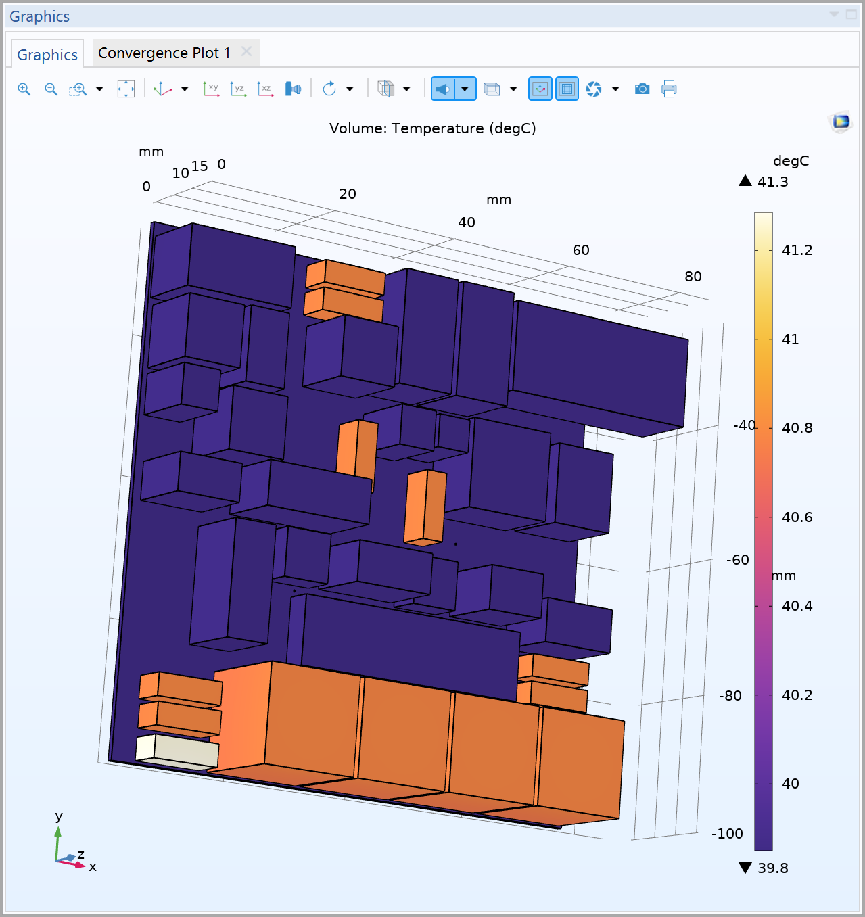
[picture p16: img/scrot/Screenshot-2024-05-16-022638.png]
  
  \caption{Результаты теплового анализа в \textit{COMSOL Multhiphysics}
    для первого варианта компоновки}
\end{figure}

Результаты теплвого анализа для второго варианта компоновки ПП в
\textit{COMSOL Multiphysics} представлены на рисунке 18.

\begin{figure}[H]
  \centering
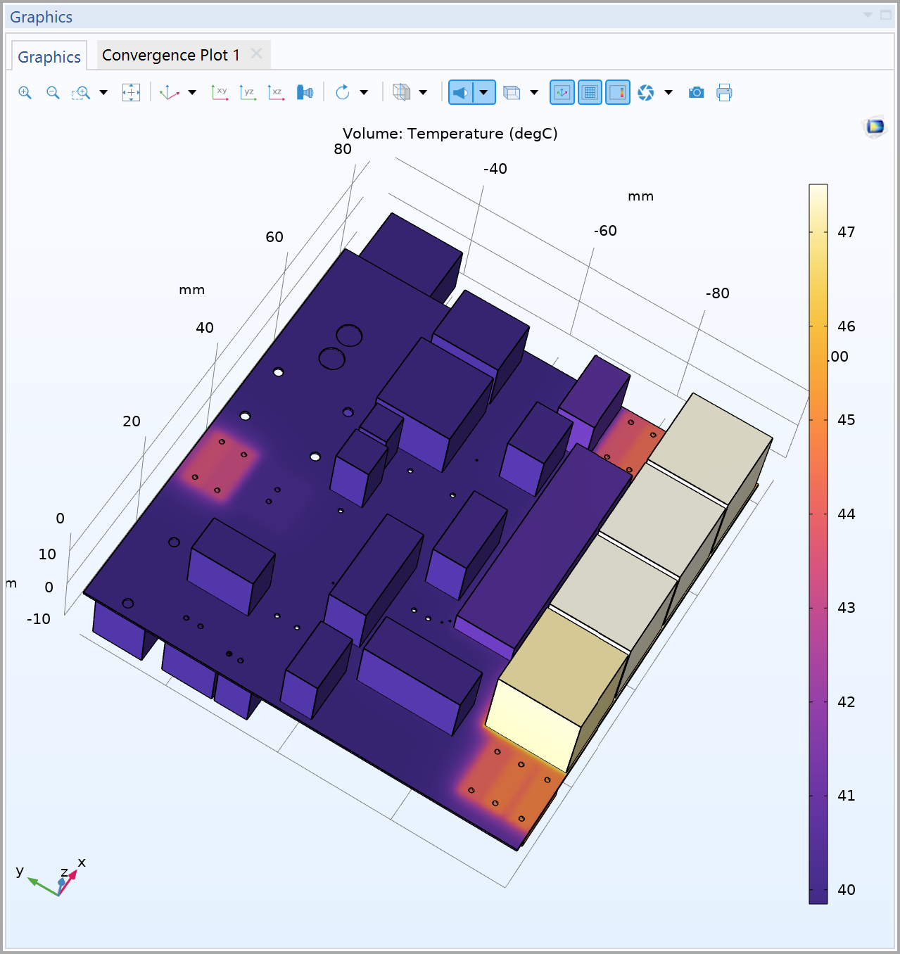
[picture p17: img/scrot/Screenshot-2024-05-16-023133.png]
  
  \caption{Результаты теплвого анализа в \textit{COMSOL Multiphysics}
  для второго варианта компоновки}

\end{figure}

Результаты тепловго анализа для третьего варианта комопновки ПП в
\textit{COMSOL Multiphysics} представлены на рисунке 19.
\begin{figure}[H]
  \centering
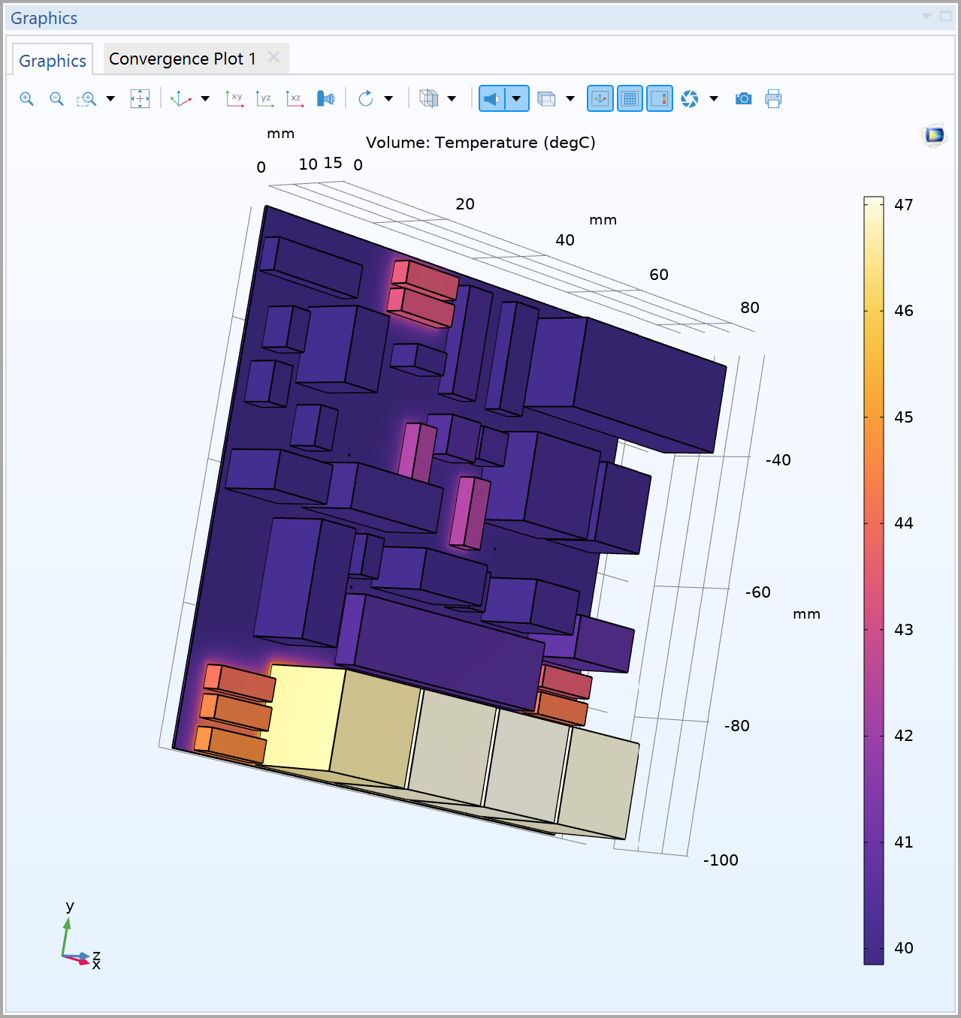
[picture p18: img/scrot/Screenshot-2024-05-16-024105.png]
  
  \caption{Результаты теплвого анализа в \textit{COMSOL Multiphysics}
  для третьего варианта компоновки}

\end{figure}

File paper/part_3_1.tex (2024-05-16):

\newpage
\section{Анализ полученных результатов моделирования}
\subsection{Обработка, анализ и интепретация данных проведенного моделирования механических процессов}

\begin{table}[H]
  \centering
  \caption{Результаты частотного анализа в \textit{SolidWorks}}
\begin{tabular}{|c|c|}
\hline
  Вариант компоновки ПП & Значение собственной частоты \\
  1 & 10,1Гц \\
  2 & 7,3 Гц \\
  3 & 7,9 Гц \\
\hline
\end{tabular}
\end{table}

Самое большое значение частоты у печатной платы выполненненой в первой компоновке. Однако можно заметить, что во всех трёх случаях частота досточно мала. 10 Гц это 10 колебаний платы в секунду, что несоотвевует уровню требуему данной печатной плате.

Однако можно считать, что в значительной степени такой результат вышел потому, что плата крепилась только за одну поверхность и была очень тонкой, так как такой вышла модель в результате экспорта.

\begin{table}[H]
  \centering
  \caption{Результаты частотного анализа в \textit{COMSOL Multiphysics}}
\begin{tabular}{|c|c|}
\hline
  Вариант компоновки ПП & Значение собственной частоты \\
  1 & 0.1 Гц \\
  2 & 13509 Гц \\
  3 & 14 Гц \\
\hline
\end{tabular}
\end{table}

Результаты анализа в \textit{COMSOL Multiphysics} так разнятся, что сделать какой-либо вывод, а не исключить данные из анализа сложно.
Но судя по всем именно значение 13509 Гц ближе всего к тому значению, которое должно было получиться при анализе печатной платы в независомости от компоновки.

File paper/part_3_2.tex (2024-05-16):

\subsection{Обработка, анализ и интепретация данных проведенного моделирования телповых процессов}

\begin{table}[H]
  \centering
  \caption{Результаты теплового анализа в \textit{SolidWorks}}
\begin{tabular}{|c|c|}
\hline
  Вариант компоновки ПП & Максимальное начение температуры в Цельсиях \\
  1 &  150 \\
  2 &  145 \\
  3 &  143 \\
\hline
\end{tabular}
\end{table}

Самое большое значение температуры у печатной платы в первой компановке.
По видимому оба решения с разнесеним компонентов по разные стороны платы
и заменой тепловыделяющих компонентов на меньшие по размеру выглядят приемлимыми для обеспечения теплового режима ПП.

Но только теплового режима  печатной платы.

\begin{table}[H]
  \centering
  \caption{Результаты теплового анализа в \textit{COMSOL Multiphysics}}
\begin{tabular}{|c|c|}
\hline
  Вариант компоновки ПП & Значение максимальной температуры в Цельсиях \\
  1 & 41.3 \\
  2 & 47,5 \\
  3 & 47 \\
\hline
\end{tabular}
\end{table}

Моделирование в \textit{COMSOL Multiphysics} показало ровно противоположный результат. При этом в качестве геометрии была импортирована модель из \textit{SOLIDWORKS} с расширением \textit{.SLPDRT}

По видимому несовпадение результатов вызвано различным методом решения применямым в данных программах.

Однако я склонен больше доверять \textit{COMSOL}, как программер специально предназначенных для таких рассчетов.

По полученным результатам и графикам можно сделать вывод,
что при проектировании печатной платы, точнее при, так называемой разводке, решение о том как расставлять компоненты можно принимать
не только основываясь на том как близко должен быть элемент с точки зрения схемотехники, но также учитывать, что рассеивающие тепло в значительной степени компоненты будут нагреваться до больших температур в тех случаях, когда будут расставлены рядом.

\newpage

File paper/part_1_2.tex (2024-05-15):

\subsection{Описание принципа работы анализируемого устройства}

Устройство представляет собой печатную плату, с установленными на ней навесным монтажом компонентами.

Сердце цепи — микроконтроллер \textit{ATmega328P},
который известен тем, что также используется в плате \textit{ArduinoUNO}.
Четыре пина \textit{GPIO} этого микрокнтроллера подключены к выводам серво-сигнала.
Серво-сигналом здесь назвам ШИМ сигнал с частотой 50 Гц.
Ширина импульса, время когда сигнал высок,
должно быть в промежутке с одной до двух милисекунд,
остальное время сигнал низок. При ширине импульса в 1,5 милисекунды сервопривод в промежуточной позиции и не вращается.
Если импульс короче, то сервопривод поворачивается в одно направление, если длиннее,
он поворачивается в противположное направление ~\cite{Elector521}.

Малогабаритные быстродействующие сервоприводы применяются в современных высокоточных системах управления подвижными объектами: рулевыми системами летательных аппаратов, автоматическими манипуляторами, роботами с подвижными элементами конструкции и др~\cite{dyakovSUBSTANTIATIONRELIABILITYSERVOMOTORS2023}.

В типичной системе контроля полета квадракоптера или дрона
пять парамеров подлежат отслеживанию:
длина четырех управляющих сервоприводами импульсов,
которые контролируют тягу, крен, тангаж и рысканье,
и напряжение питания.
В случае сложной конструкции,
например при разработке полётного контроллера,
данный тестовый стенд позволяет наблюдать получаемый сигнал ~\cite{Elector521}.

Данный тестовый стенд может работать в двух режимах,
выбираемых переключателем:
\begin{enumerate}[label={\arabic*.}]
\item Ручной режим. В нём тестовый стенд генерирует импульсы для четырех сервоприводов или полетного контроллера. Длина импульсов контролируется четырьмя потенциометрами. В этом режиме тестовый стенд обеспечивает питание сервоприводов или полетного контроллера и питание от квадрокоптера не должно быть подключено к ним. Напряжение питания тестового стенда должно быть между 7,5 или 12 Вольт.
\item Режим ввода. В нём измеряются длины имульсов поступающих от приёмника сигнала. Сигналы потом поступают на выводы, подключенные к полётному контроллеру или сервпоприводам.
  В этом режиме тестовый стенд и сервоприводы получают питание от источника питания от квадрокоптера. Получаемое питание не должно превышать 7.49 Вольт и тестовый стенд не должен быть подключен к своему истчонику питания. Также четыре канада должны быть подключены, иначе светодиод и зуммер просигналируют об ошибке.  
\end{enumerate}

Тестовый стенд измеряет длину контрольных импульсов и даёт информацию о качестве источника питания.
Данное устройство может быть подключено между приёмником дистанционного управления и полетным контроллером дрона,
или между полетным контроллером и сервоприводами.
Информацию о сигналах выводимых к сервоприводам тестовый стенд выводит на \textit{OLED} дисплей подключенный, через \textit{I2C} интерфейс.
Дисплей показывает продолжительсность импульсов графиком из четырёх кривых вмести с их численным значением в микросекундах ~\cite{Elector521}.

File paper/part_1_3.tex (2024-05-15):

\subsection{Анализ электрической принципиальной схемы устройства}

Поскольку статья о тестовом стэнде написана в иностранном журнале, схема электрическая принципиальная в нём выполнена не по отечественному ГОСТ.

\begin{figure}[h]
  \centering
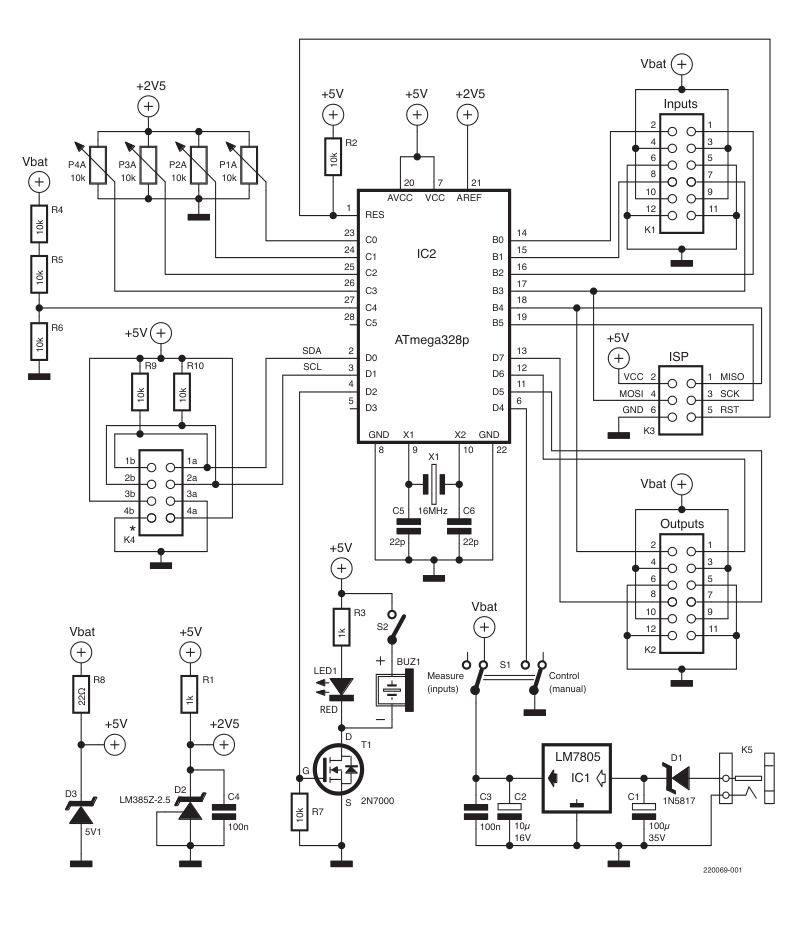
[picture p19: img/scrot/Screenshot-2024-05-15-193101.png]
  
  \caption{Электрическая принципиальная схема устройства}
\end{figure}

На приложенной схеме в центре видно микроконтроллер подключенный к кристаллу с частотой колебаний 16 Мгц, который в свою очередь подключен к конденсаторам C5 и С6. Четыре пина \textit{GPIO} — PB0-PB3 подключены  к разъёму K1. Выводы для серво сигнала — PD5, PD6, PD7 и PB4 подключены к разъёму K2. Два этих раззъёма разведены таким образом, что к ним можно подключлить стандартный для сервопривода кабель ~\cite{Elector521}.

Четыре потенциометра подключеный к аналоговым входам микроконтроллера PC0-PC3. Питание подключается через делитеть напряжения из резисторов R4-R6 к аналоговому входу PC4. Отношение между суммой сопротивлений R4, R5 и сопротивлением R6 должно быть 2 к 1 соотвественно, но их абсолютные значения не критичны. Использование трёх резисторов одного значения облегчает их сортировку для точности ~\cite{Elector521}.

Для того чтобы измерять напряжение источника питания нужен аналогово цифровой преобразователь и 
опорное напряжение не относящиеся к самому напрежению питания.
В микроконтроллере уже есть опорное напряжение в 1,1 Вольт, однако это значение несколько мало. И поэтому используется источник опорного напряжения LM385-2.5 обозначенный как D2, как внешнее опорное напряжение в 2,5 Вольта. Этот элемент более точен, чем простой двухконтактный зенеровский диод ~\cite{Elector521}.

К коннектору K4 подключается \textit{OLED} дислпей по типу SSD1306.
У дисплея должен быть порт \textit{I2C}, но он будет подключаться к порту \textit{I2C} микроконтроллера, но к компонентам PD0 и PD1. Шина \textit{I2C} эмулируется программным обеспечением. Так выходит из-за того, что шина \textit{I2C} на данном микроконтроллере находится на том же пине, что и аналоговый вход PC4, который уже используется для измерения напряжения питания ~\cite{Elector521}.

Резисторы R9 и R10 это подтягивающие резисторы для шины \textit{I2C}.

Ползунковый переключатель S1 типа \textit{DPDT} используется для выбора режима работы тестового стенда. В ручном режиме переключатель соединяет напряжения питания номиналом 5 Вольт и коннекторы сервоприводов. В режиме ввода он предовтращает неправильное включение напряжений ~\cite{Elector521}.

Возможно, что решение в части подключение дисплея к данному тестовому
стенду и не является самым элегантным. Однако сама по себе схема
достаточно проста,состоит из небольшого числа комопонентов, но тем не
менее может работать в нескольких режимах и схемах включения, что выглядит как положительные черты относительно того в каких вариантах использования оказывается устройство.

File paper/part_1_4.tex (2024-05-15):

\subsection{Определение параметров воздействующих дестабилизирующих факторов протекающих физических процессов}

РЭС эксплуатируются в условиях воздействия на них целого ряда
систематических и случайных факторов. Систематические факторы определяют рабочие функции аппаратуры и могут быть учтены в процессе разработки,
а случайные факторы по своему характеру и времени воздействия проявляются случайным образом, в связи с чем учет их влияния в процессе разработки достаточно затруднен ~\cite{Alexeev2013}.

Факторы делятся на объективные, не зависящие от человека, и субъективными, то есть зависящими от действий конструктора или использующего данный тестовый стенд оператора.

По характеру воздействия на РЭС объективные факторы разделяются на климатические, механические и другие.

Параметры климатических факторов принимают значения в соотвестиве с учетом УХЛ 4.2 ГОСТ 15150-69.

Параметры механических факторов же принимают значения, выбранные разработчиком.

Наиболее вероятным механическим фактором для данного устройства будет воздействие вибрации, в следствии работы подключаемых сервоприводов.

Во всей схеме практически не встречаются компоненты с большим тепловыделением. Так например найти коэффициент \textit{TDP} для микроконтроллера не предстовляется возомжным, потому что среди производителй микроконтроллеров, в отличие от производителей микропроцессоров не принято не то что рассчитывать этот коэффициент рассеивания теплоты, а даже закладывать в этот компоенент схемы возможности какого-либо его нагрева.

Однако это ни в коем случае не означает то, что ни один из элементов не будет нагреваться. Напротив при работе любого электронного прибора какая-то часть потребляемой мощности рассеивается как тепло.
Но если рассматривать отношение мощности потребляемой и рассеиваемой как тепло, то можно понять, что самым простым оно будет у резисторов.

По видимому, можно взять информацию о мощности резистора и принять её за мощность рассеиваемую в виде теплоты ~\cite{HeatDissipatedResistors}.

Примерно таким же образом было сделано допущение о схожести в вопросе рассеиваемой мощности между резисторами и потенциометрами.

Исходя из всего вышеописанного был сделан вывод о необходимости проведения частотного анализа и термического анализа.

\newpage

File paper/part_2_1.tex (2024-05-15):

\section{Моделирование физических процессов, воздействующих на устройство}
\subsection{Обоснование выбора прикладного программного обеспечения для моделирования физических процессов}

Программ для проведения инженерных расчетов не так уж много. И итак ограниченный выбор пал на три программы: \textit{SOLIDWORKS SIMULATION},
\textit{ANSYS}, \textit{COMSOL Multiphysics}. Дело в том, что все три эти программы, чаще всего и используются для МКЭ расчетов. Хотя, это по большей части относится к \textit{COMSOL Multiphysics} и \textit{ANSYS}, а \textit{SOLIDWORKS} удобен и сам по себе как средство для конвертации, работы и упрощения с трёхмерными параметрическими моделями.
Возможность моделировать в нём можно считать приятным дополненим к его функционалу, которое тем не менее видится как обязательное к использованию в этой работе.

Популярность таких программ как \textit{COMSOL Multiphysics} и \textit{ANSYS} в кругах инженеров позволяет рассчитывать на наличие большого количетства обучающих материалов по ним, в том числе созданных не только самой компанией осуществляющей разработку программы.

Кроме того обе программы сами по себе обладают огромным набором возможностей для проведения симуляции и зачастую имеют некоторый аналог интерфейса трёхмерных параметрических САПР типа \textit{SOLIDWORKS}, который позволяет интерактивно взаимодествовать с геометрией модели, материалом и сеткой модели.

Также особенно хочется отметить доступность и качество документации доступной на официальном сайте \textit{COMSOL}.

Совокупнсот вышеописанных качеств делает эти программы достойным выбором для проведения исследования.

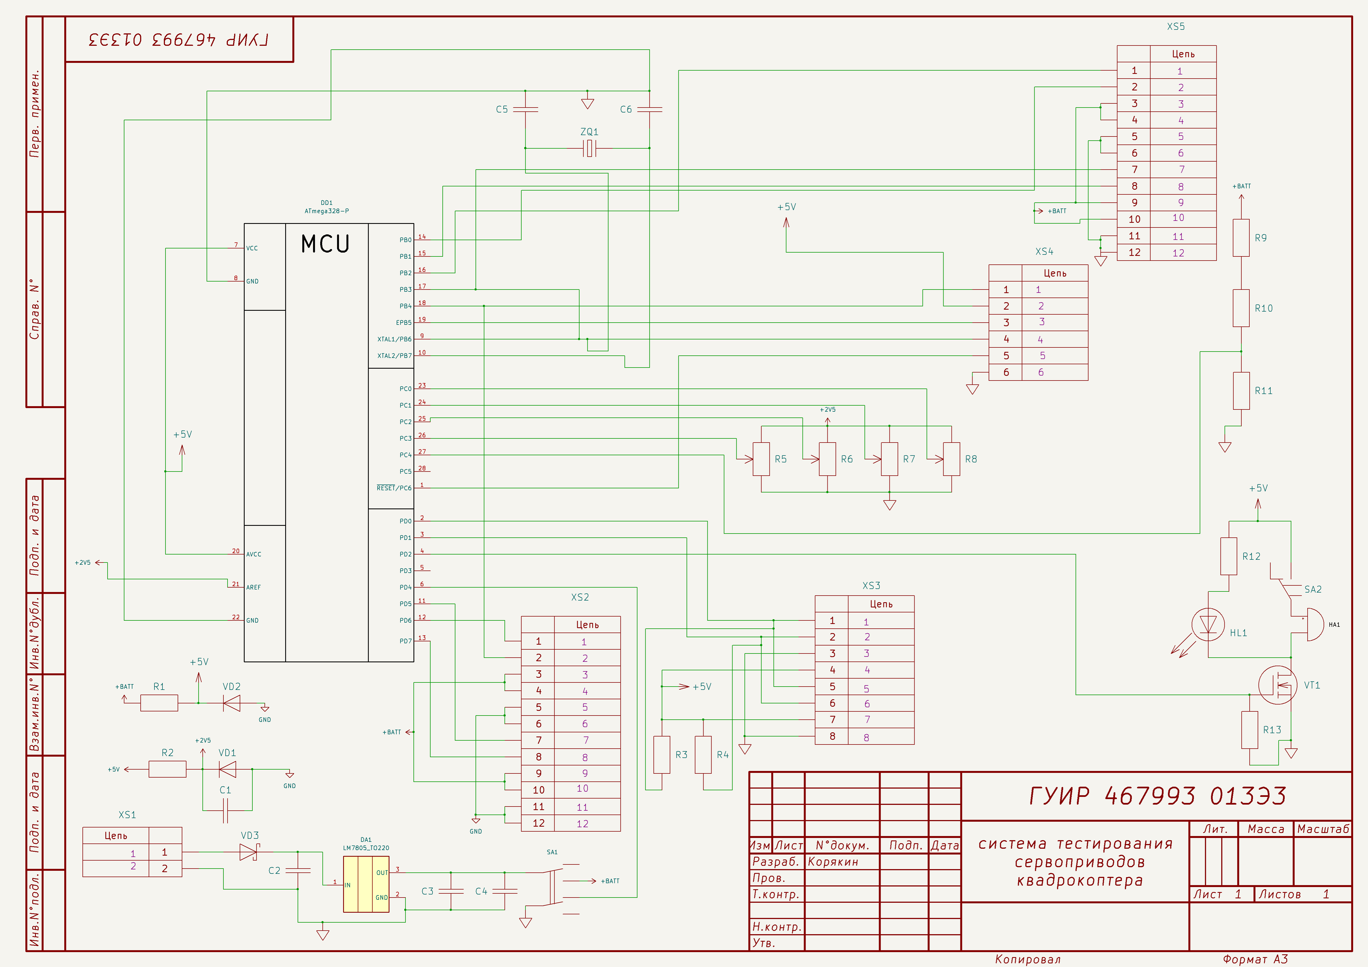
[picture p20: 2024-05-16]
img/my_schematic.png

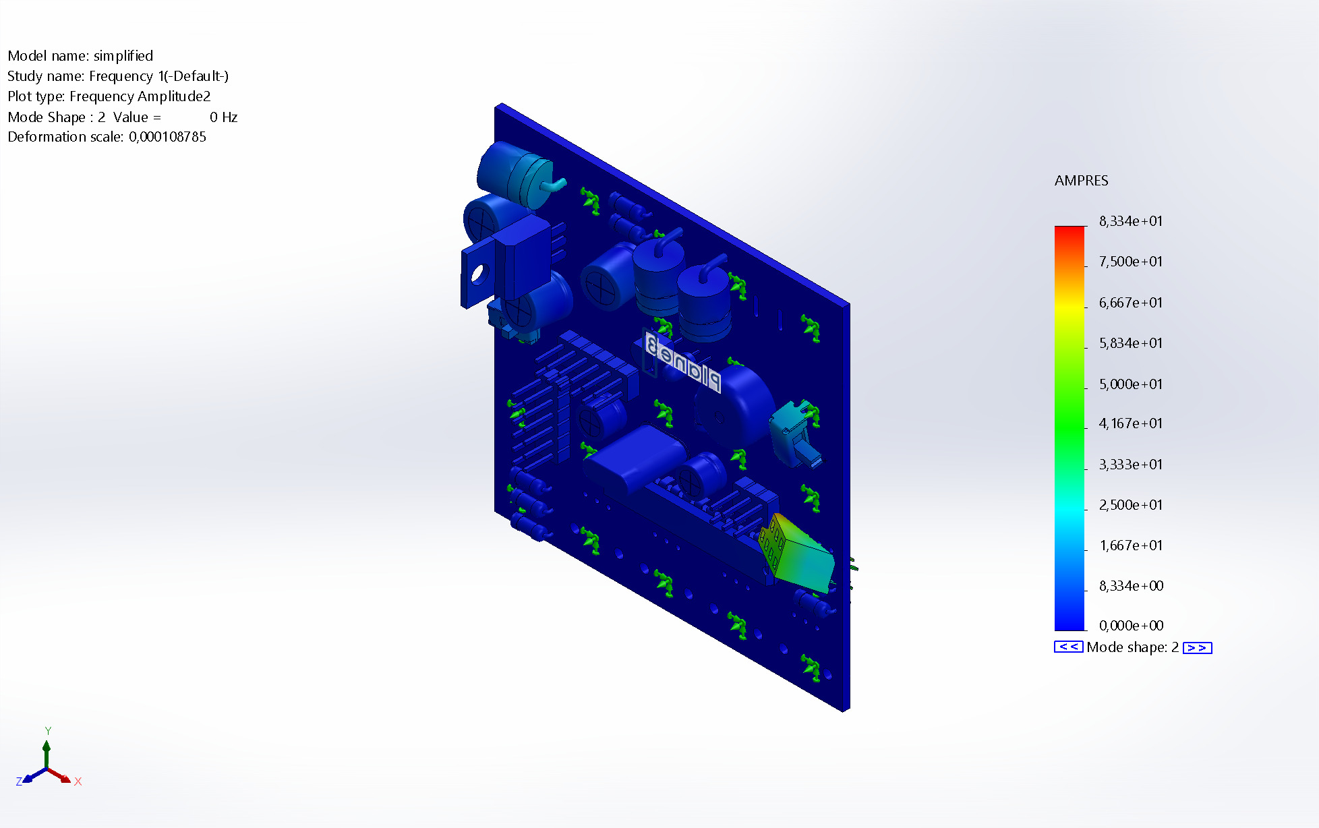
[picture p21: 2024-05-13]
img/first_attempt/simplified-Frequency 1-Amplitude-Amplitude2.jpg

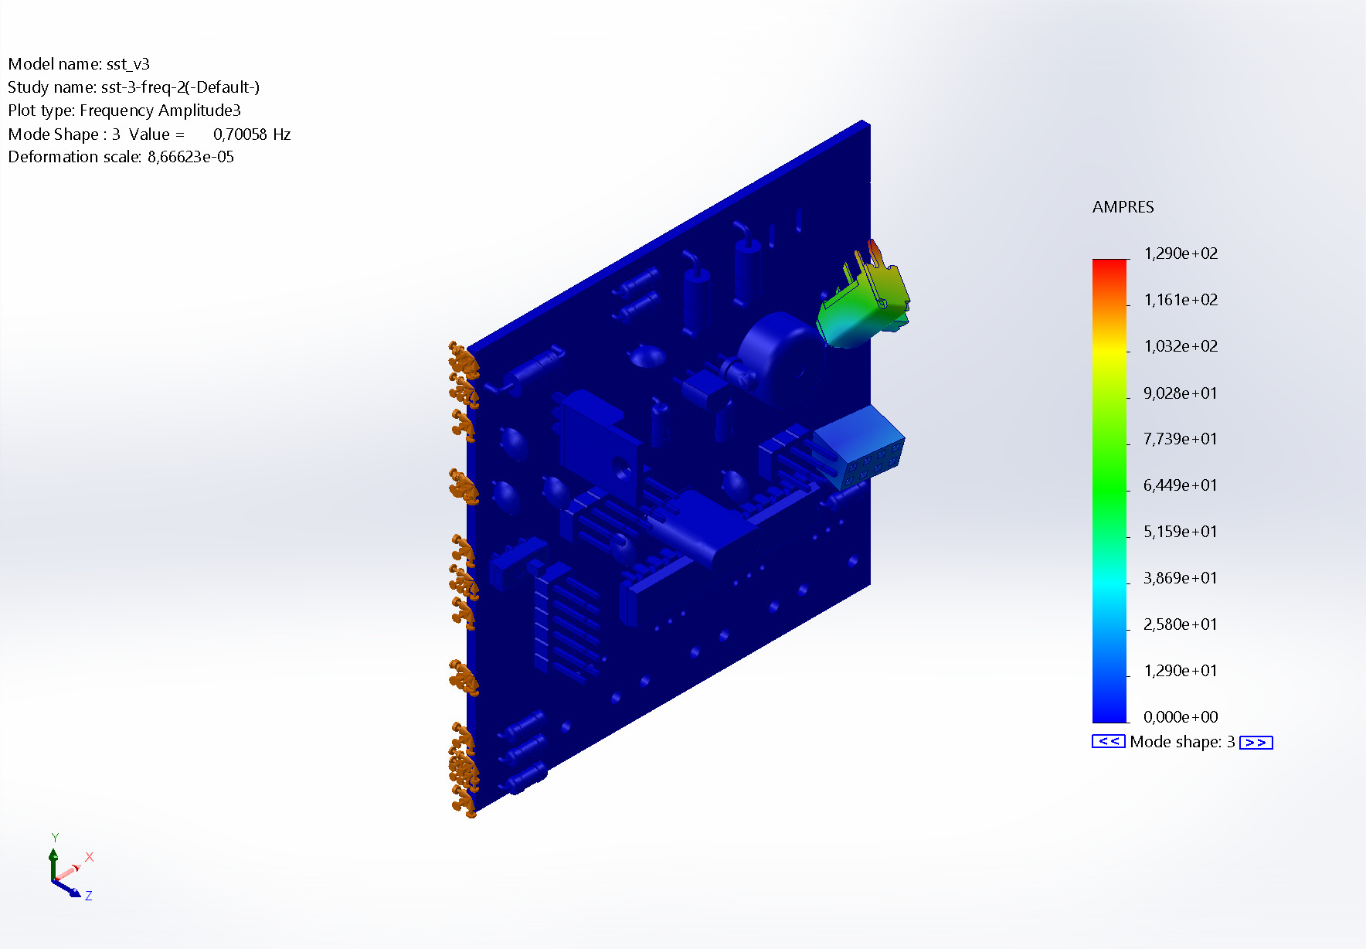
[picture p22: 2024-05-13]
img/first_attempt/sst_v3-sst-3-freq-2-Amplitude-Amplitude3.jpg

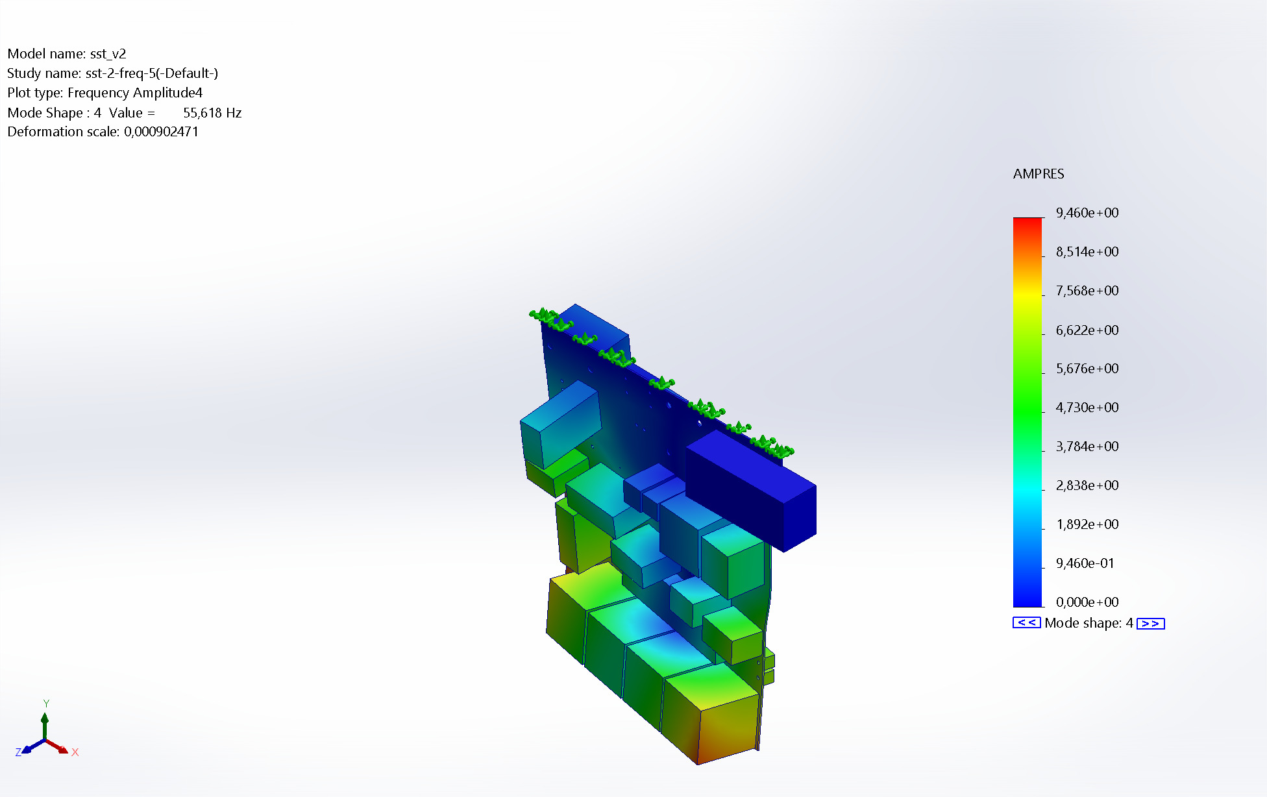
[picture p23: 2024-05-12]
img/sst-2/freq/sst_v2-sst-2-freq-5-Amplitude-Amplitude4.jpg

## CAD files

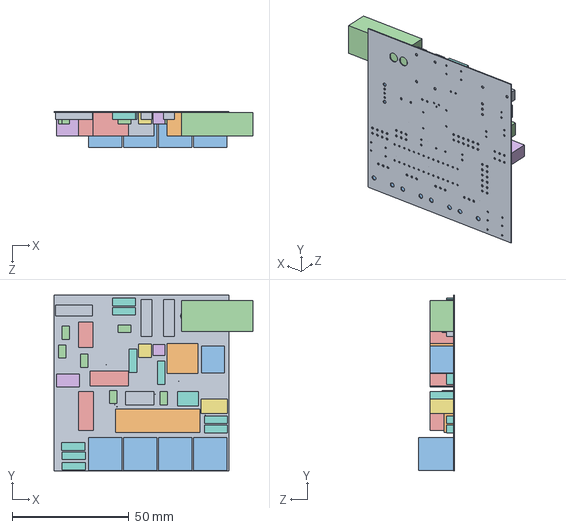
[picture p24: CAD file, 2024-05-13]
step_export/sst_v3.STEP
85.4 x 75.5 x 15.4 mm

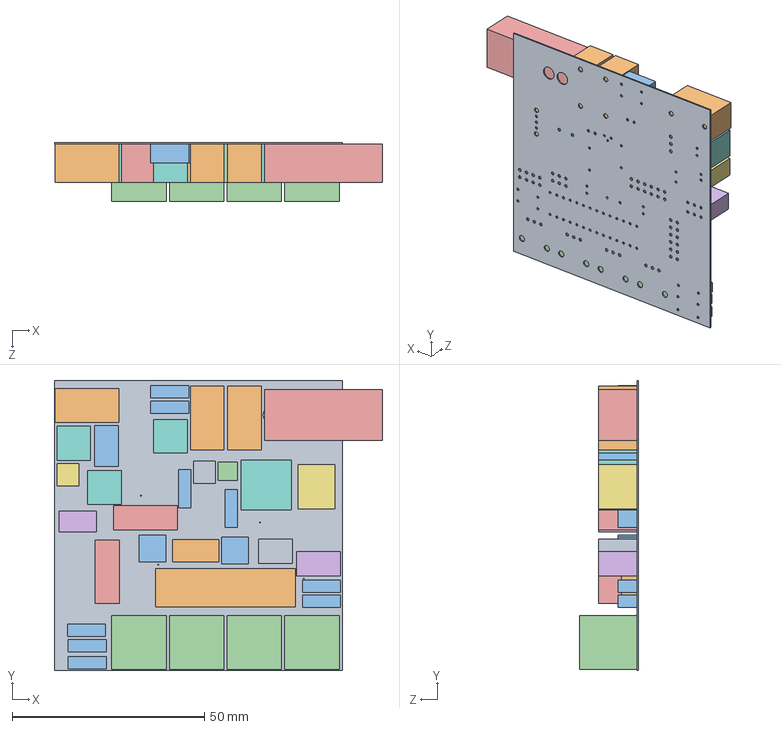
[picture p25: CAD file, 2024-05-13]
step_export/sst.STEP
85.4 x 75.5 x 15.4 mm

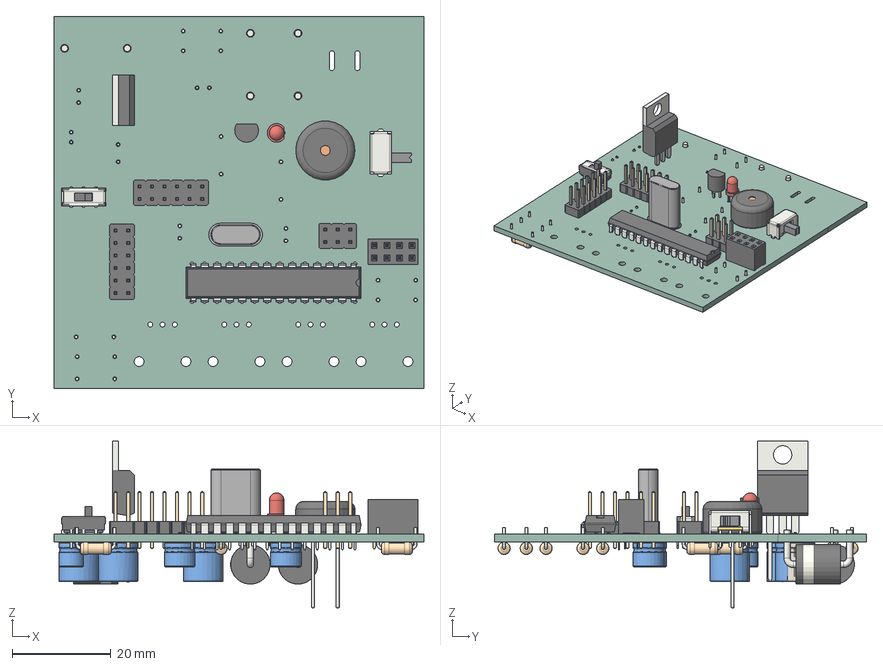
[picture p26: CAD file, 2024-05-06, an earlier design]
kicad_sst/step_models/sst_v2.step
75.0 x 75.5 x 33.8 mm
PinHeader_2x06_P254mm_Vertical x 2
CuK_JS202011CQN_DPDT_straight
LED_D3.0mm
TO-92_Narrow
DIP-28_W7.62mm
PinSocket_2x04_P254mm_Vertical
Crystal_HC49-U_Vertical
TO-220-3_Vertical
SW_Slide_SPDT_Angled_CK_OS102011MA1Q
PinHeader_2x03_P254mm_Vertical
Buzzer_TDK_PS1240P02BT_D122mm_H65mm
R_Axial_DIN0207_L63mm_D25mm_P762mm_Horizontal x 9
CP_Radial_D80mm_P250mm x 2
D_5KPW_P12.70mm_Horizontal x 3
CP_Radial_D80mm_P350mm
C_Radial_D63mm_H50mm_P250mm x 2
CP_Radial_D50mm_P200mm
sst_v2_PCB

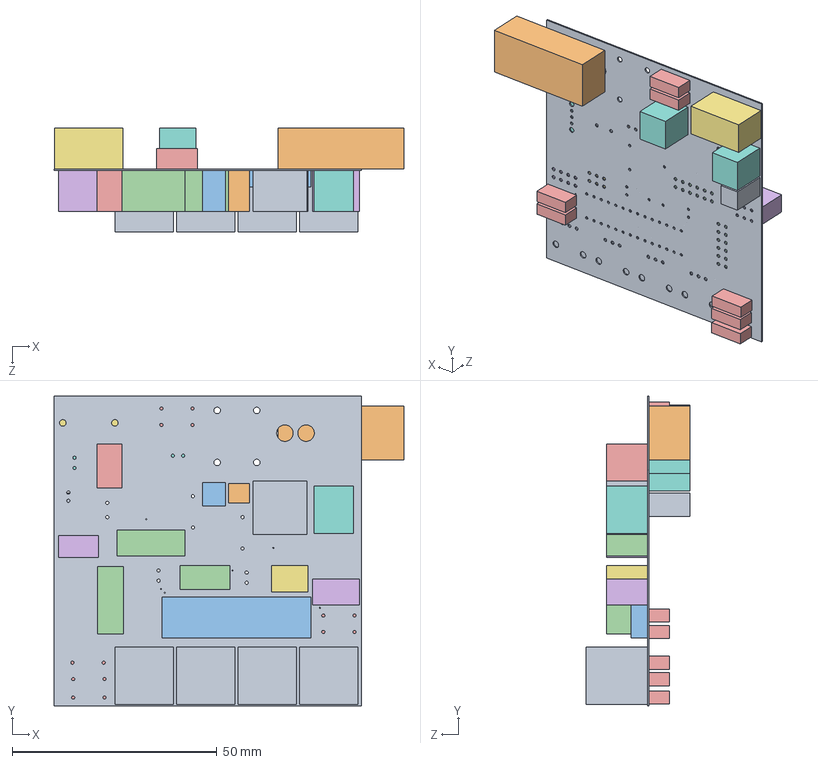
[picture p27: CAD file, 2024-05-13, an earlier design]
step_export/sst_v2.STEP
85.4 x 75.5 x 25.4 mm

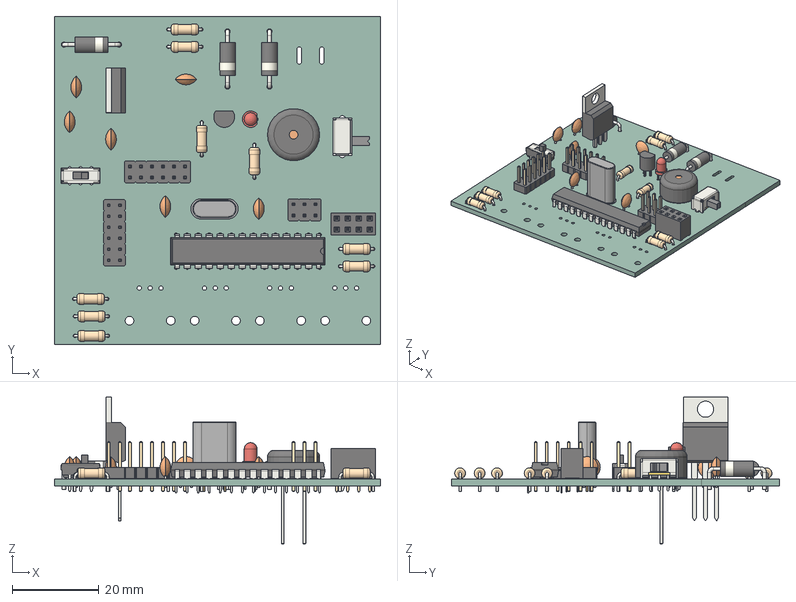
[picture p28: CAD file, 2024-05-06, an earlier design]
kicad_sst/step_models/sst_v3.step
75.0 x 75.5 x 33.8 mm
R_Axial_DIN0207_L63mm_D25mm_P762mm_Horizontal x 9
C_Disc_D50mm_W25mm_P250mm x 6
PinHeader_2x06_P254mm_Vertical x 2
CuK_JS202011CQN_DPDT_straight
D_DO-15_P12.70mm_Horizontal x 3
LED_D3.0mm
TO-92_Narrow
DIP-28_W7.62mm
PinSocket_2x04_P254mm_Vertical
Crystal_HC49-U_Vertical
TO-220-3_Vertical
SW_Slide_SPDT_Angled_CK_OS102011MA1Q
PinHeader_2x03_P254mm_Vertical
Buzzer_TDK_PS1240P02BT_D122mm_H65mm
sst_v3_PCB

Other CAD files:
kicad_sst/step_models/sst.step

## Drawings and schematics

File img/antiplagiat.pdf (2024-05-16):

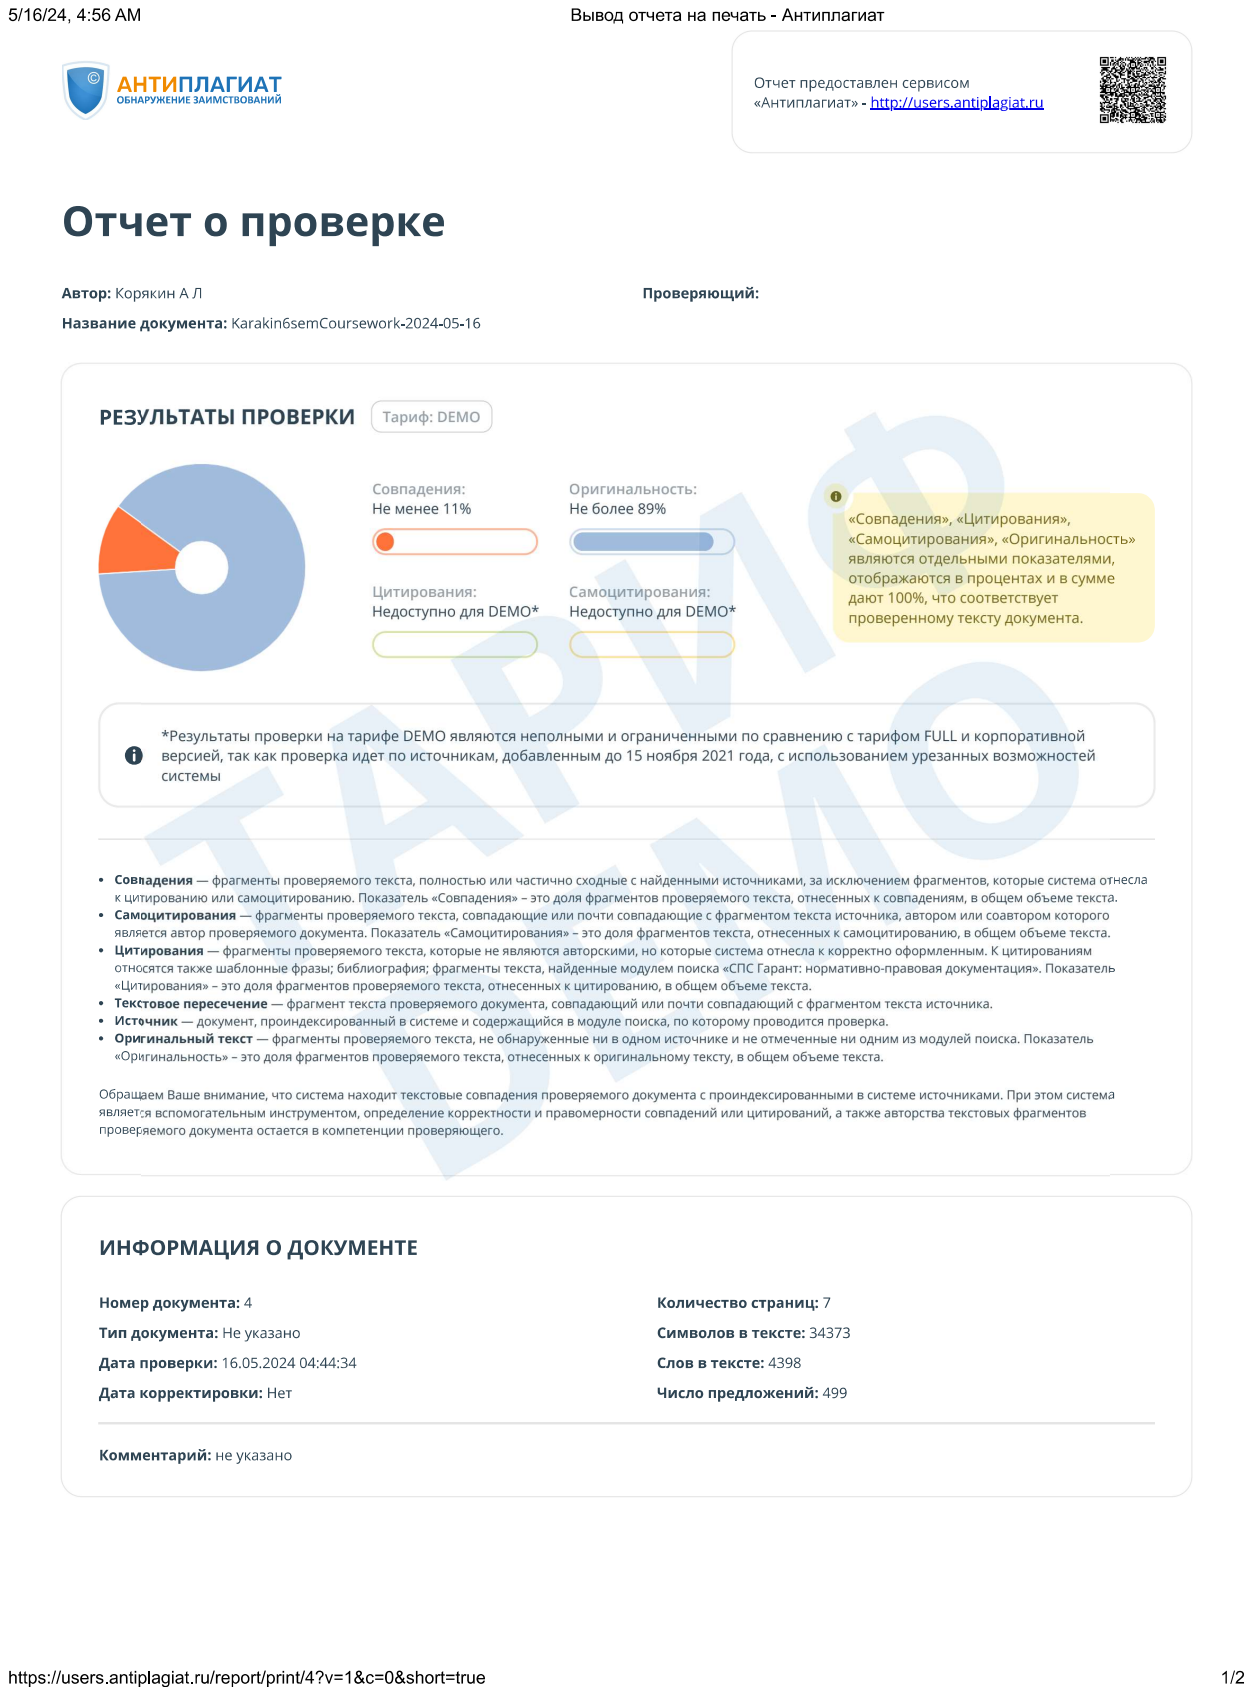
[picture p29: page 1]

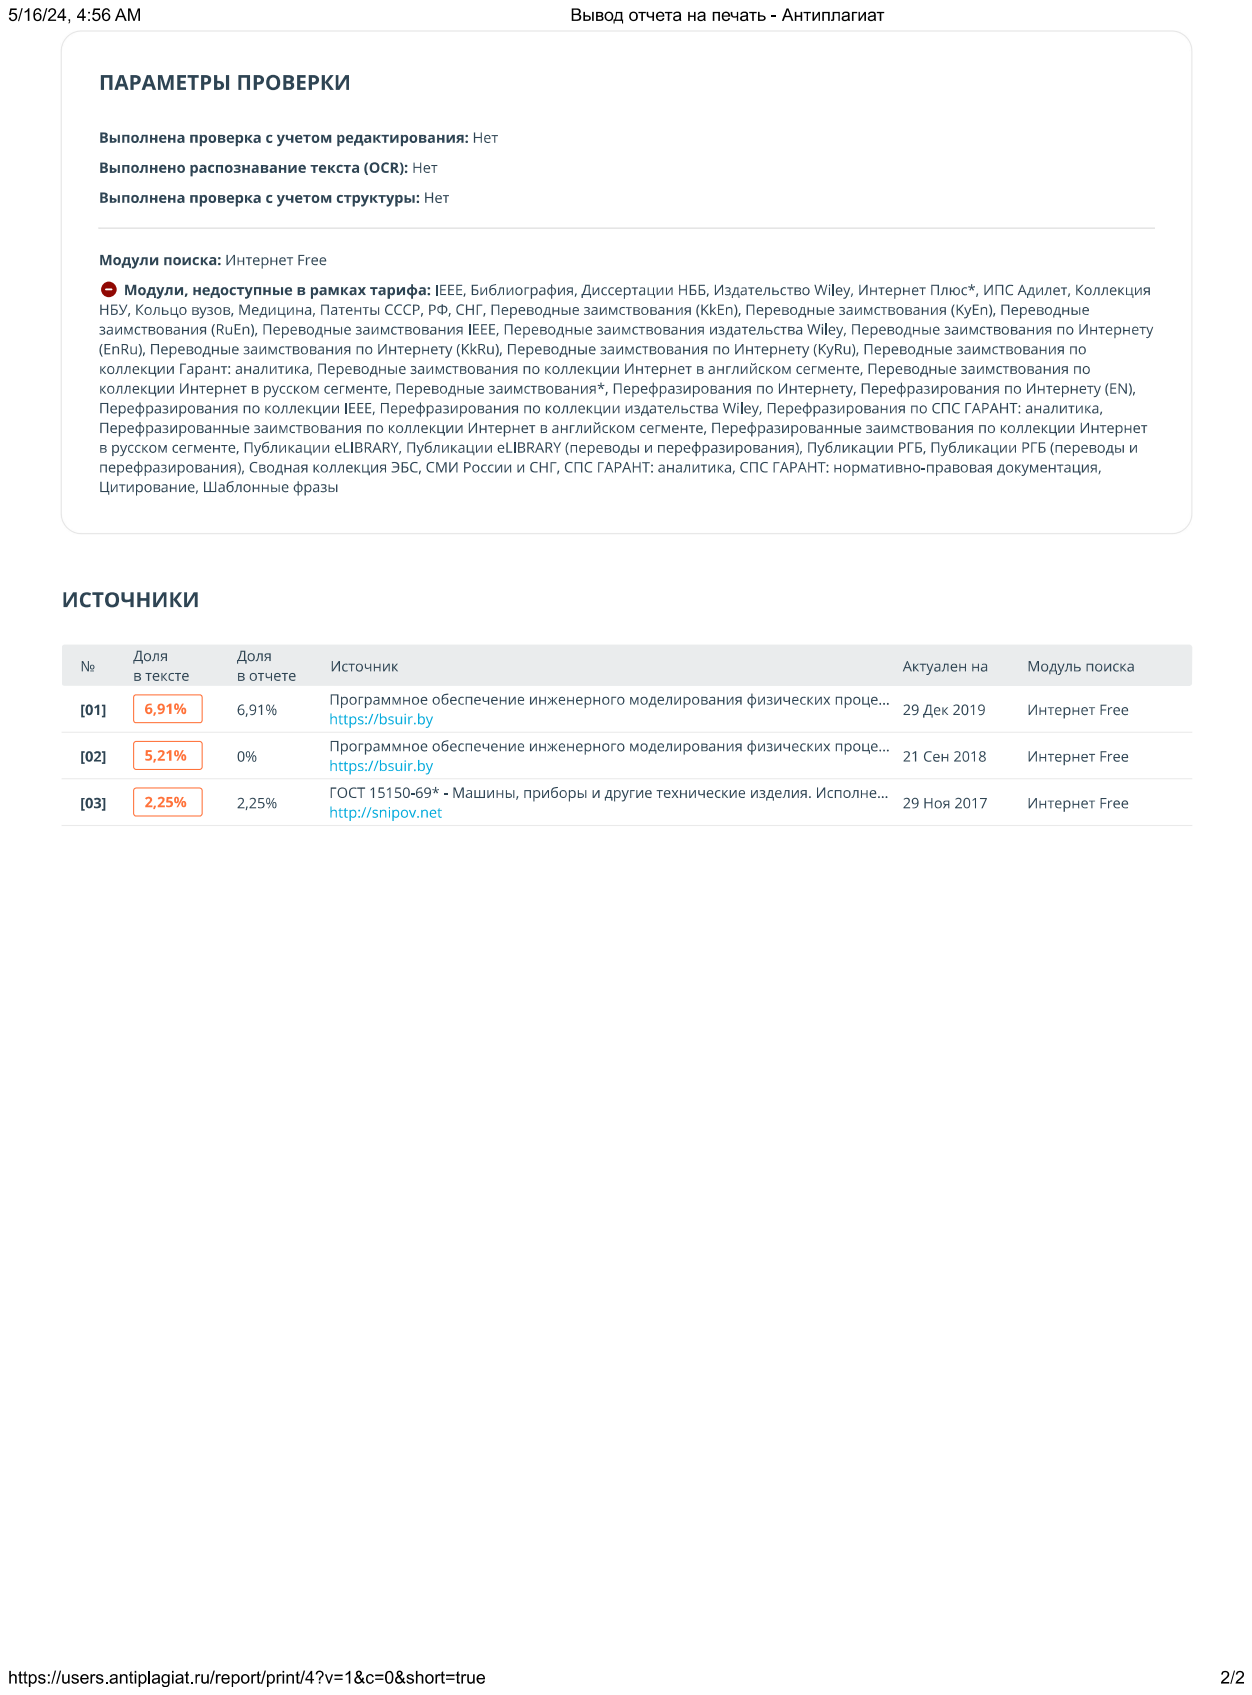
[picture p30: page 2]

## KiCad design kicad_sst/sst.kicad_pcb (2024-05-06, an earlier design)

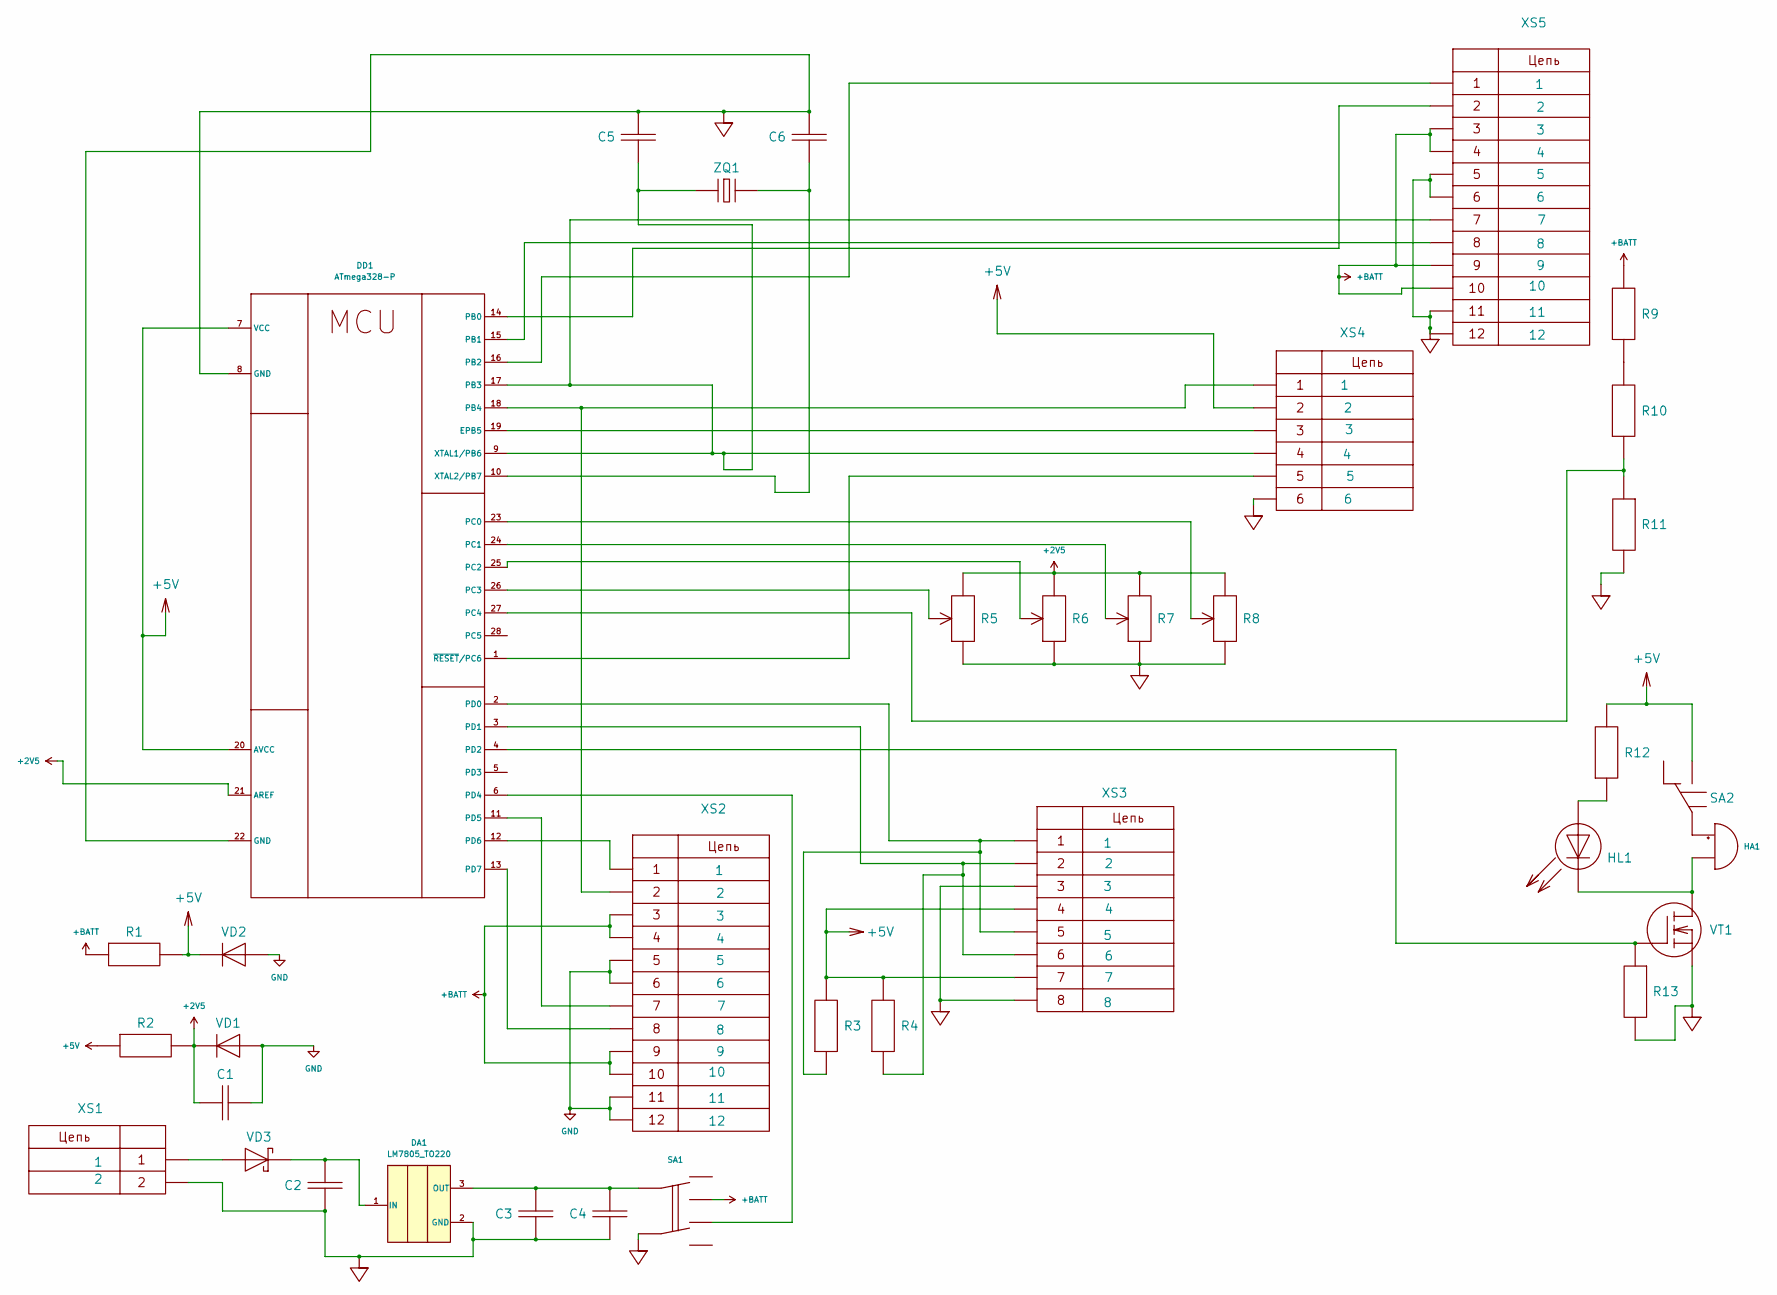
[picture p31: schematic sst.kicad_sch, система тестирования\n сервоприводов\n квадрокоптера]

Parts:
C1, C4: C; CP_Radial_D8.0mm_P2.50mm
C2: C; CP_Radial_D8.0mm_P3.50mm
C3: C; CP_Radial_D5.0mm_P2.00mm
C5, C6: C; C_Radial_D6.3mm_H5.0mm_P2.50mm
DA1: LM7805_TO220; TO-220-3_Vertical
DD1: ATmega328-P; DIP-28_W7.62mm
HA1: Buzzer; Buzzer_TDK_PS1240P02BT_D12.2mm_H6.5mm
HL1: HL_LED; LED_D3.0mm
R1, R2, R3, R4, R9, R10, R11, R12, R13: R; R_Axial_DIN0207_L6.3mm_D2.5mm_P7.62mm_Horizontal
R5, R6, R7, R8: R_POT; Potentiometer_TT_P0915N
SA1: SW_CK_JS202011CQN_DPDT_Straight
SA2: SA_SPDT; SW_Slide_SPDT_Angled_CK_OS102011MA1Q
VD1, VD2: VD; D_5KPW_P12.70mm_Horizontal
VD3: VD_Schottky; D_5KPW_P12.70mm_Horizontal
VT1: 2П7240; TO-92
XS1: CONN_2; BarrelJack_SwitchcraftConxall_RAPC10U_Horizontal
XS2, XS5: CONN_12; PinHeader_2x06_P2.54mm_Vertical
XS3: CONN_8; PinSocket_2x04_P2.54mm_Vertical
XS4: CONN_6; PinHeader_2x03_P2.54mm_Vertical
ZQ1: ZQ_CRYSTAL; Crystal_HC49-U_Vertical

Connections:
+2V5: C1.1, DD1.21 (AREF), R2.2, R5.3, R6.3, R7.3, R8.3, VD1.1 (K)
+5V: DD1.7 (VCC), DD1.20 (AVCC), R1.2, R2.1, R3.2, R4.2, R12.2, SA2.2, VD2.1 (K), XS3.4, XS3.7, XS4.2
+BATT: R1.1, R9.2, SA1.4, XS2.3, XS2.4, XS2.9, XS2.10, XS5.3, XS5.4, XS5.9, XS5.10
GND: C1.2, C2.2, C3.2, C4.2, C5.1, C6.1, DA1.2 (GND), DD1.8 (GND), DD1.22 (GND), R5.1, R6.1, R7.1, R8.1, R11.2, R13.2, SA1.2, VD1.2 (A), VD2.2 (A), VT1.1 (S1), XS1.2, XS2.5, XS2.6, XS2.11, XS2.12, XS3.3, XS3.8, XS4.6, XS5.5, XS5.6, XS5.11, XS5.12
unnamed: C2.1, DA1.1 (IN), VD3.1 (K)
unnamed: C3.1, C4.1, DA1.3 (OUT), SA1.1
unnamed: DD1.19 (EPB5), XS4.3
unnamed: DD1.14 (PB0), XS5.2
unnamed: DD1.15 (PB1), XS5.8
unnamed: DD1.16 (PB2), XS5.1
unnamed: C5.2, DD1.9 (XTAL1/PB6), DD1.17 (PB3), XS4.4, XS5.7, ZQ1.1
unnamed: DD1.18 (PB4), XS2.2, XS4.1
unnamed: DD1.23 (PC0), R8.2
unnamed: DD1.24 (PC1), R7.2
unnamed: DD1.25 (PC2), R6.2
unnamed: DD1.26 (PC3), R5.2
unnamed: DD1.27 (PC4), R10.1, R11.1
unnamed: DD1.2 (PD0), R3.1, XS3.1, XS3.5
unnamed: DD1.3 (PD1), R4.1, XS3.2, XS3.6
unnamed: DD1.4 (PD2), R13.1, VT1.2 (G1)
unnamed: DD1.6 (PD4), SA1.5
unnamed: DD1.11 (PD5), XS2.7
unnamed: DD1.12 (PD6), XS2.1
unnamed: DD1.13 (PD7), XS2.8
unnamed: C6.2, DD1.10 (XTAL2/PB7), ZQ1.2
unnamed: DD1.1 (~RESET/PC6), XS4.5
unnamed: HA1.1 (+), SA2.1
unnamed: HA1.2 (-), HL1.1 (K), VT1.3 (D1)
unnamed: HL1.2 (A), R12.1
unnamed: R9.1, R10.2
unnamed: VD3.2 (A), XS1.1

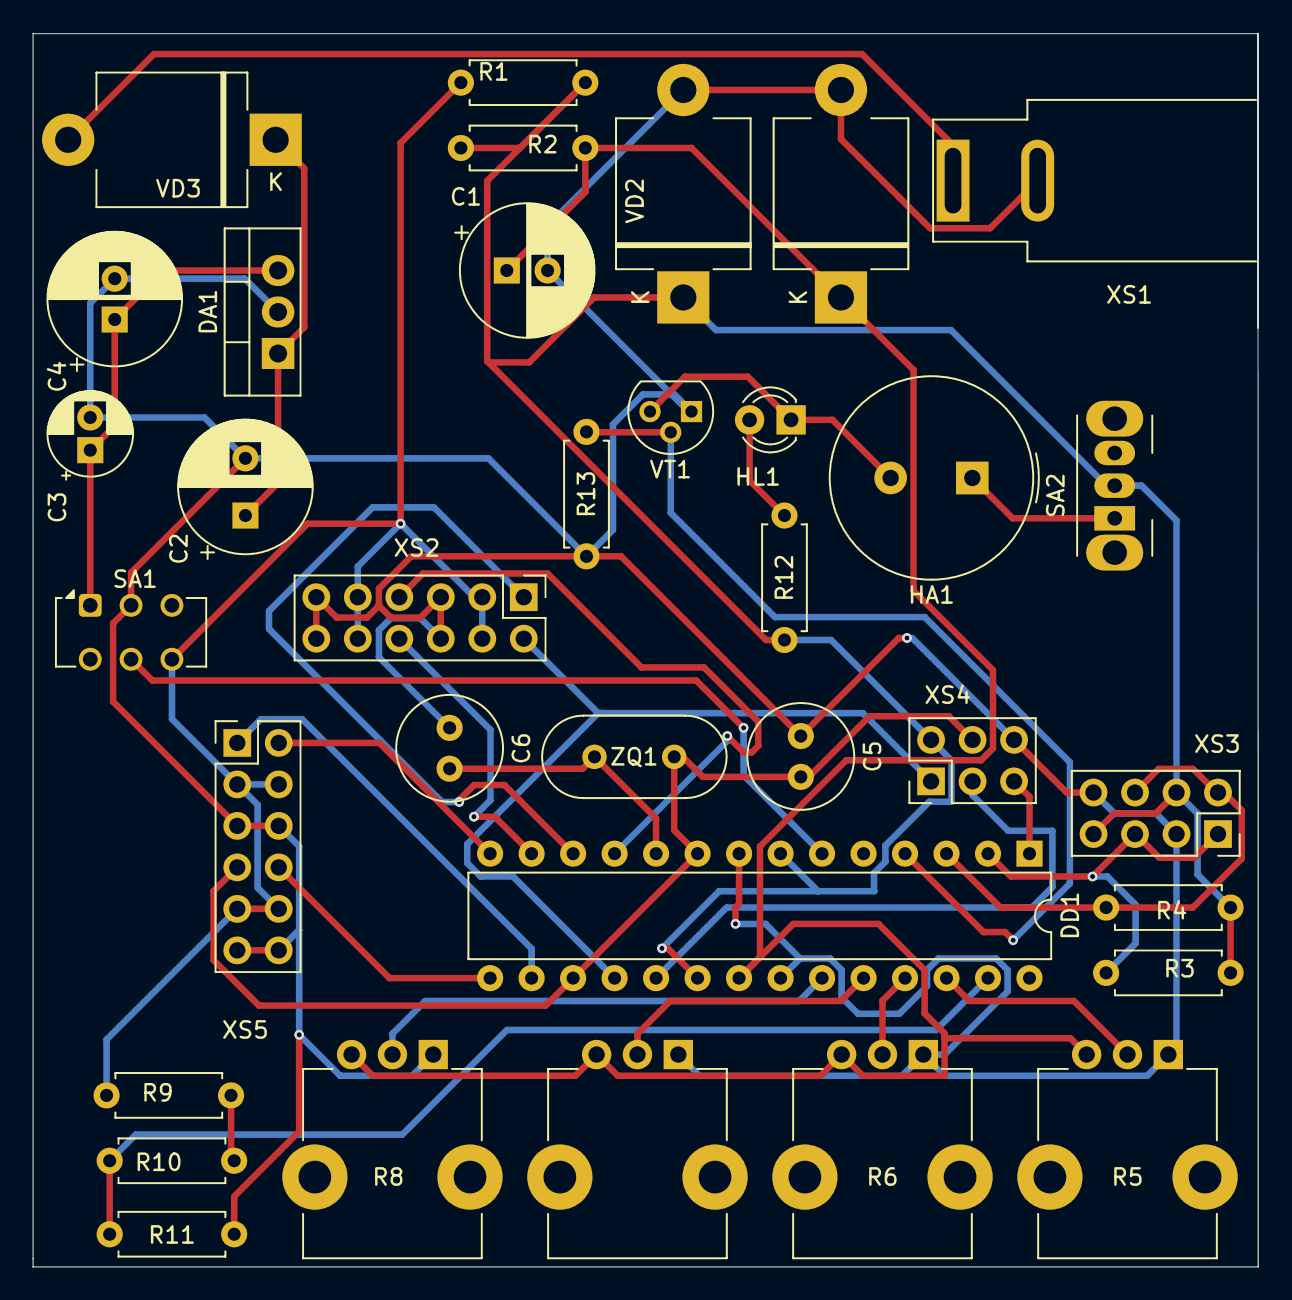
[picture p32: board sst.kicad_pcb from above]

Board: 2 copper layers, 75.0 x 75.5 mm, 35 parts (0 on the bottom side), 31 nets.

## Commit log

2024-02-29 Первая версия перечня элементов
2024-02-29 Шрифт Open GOST A для чертежей
2024-02-29 README с инфой по используемуму софту
2024-03-01 Мой класс с прошлого курсового
2024-03-01 Начало пояснительной записки, дали 5%
2024-03-15 Initial commit with Altium Project, created schematic lib
    [Karakin6semPCB.PrjPcb, STT.SchDoc, STT_Schlib.SchLib]
2024-03-15 ЕСКД Класс на схеме электрической принципальной
    [STT.SchDoc]
2024-03-15 SST — Super Servo Tester
    [Karakin6semPCB.PrjPcb, SST.SchDoc, SST_Schlib.SchLib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]
2024-03-24 Xtal now has QX designator like in GOST
    [SST_Schlib.SchLib]
2024-03-24 Укрупнил микроконтроллер и поменял местами его выводы
    [SST_Schlib.SchLib]
2024-03-24 Разместил на схеме микроконтроллер и кварцевый резонатор
    [SST.SchDoc]
2024-03-24 Поставил регулятор напряжения на принципальную схему
    [SST.SchDoc]
2024-03-24 rename ZX to ZQ on Xtal
    [Karakin6semPCB.PrjPcb, SST.SchDoc, SST_Schlib.SchLib]
2024-03-25 Changed LED and MOSFET
    [SST_Schlib.SchLib]
2024-03-25 Added connector for 6,8,12 pins
    [SST_Schlib.SchLib]
2024-03-25 Updated potentiometr
    [SST_Schlib.SchLib]
2024-03-26 All work done on schematics yesterday 2024-03-25
    [SST.SchDoc, SST_Schlib.SchLib]
2024-03-26 Placed almost everything on the scheme
    [SST.SchDoc]
2024-03-26 Enumerated all components and changed GND
    [SST.SchDoc]
2024-03-26 Enumerate all elements in project
    [Karakin6semPCB.PrjPcb, SST.SchDoc]
2024-03-26 Enumerated and connected all
    [SST.SchDoc]
2024-03-26 Fixed connection between XS3 and MCU
    [SST.SchDoc]
2024-03-26 Commit to keep changes in scheme
    [SST.SchDoc]
2024-03-26 Добавил на принципальную схему те части, которые не соеденены с микроконтроллером, пронумеровал всё
    [Karakin6semPCB.PrjPcb, SST.PcbLib, SST.SchDoc]
2024-03-29 Сменил форму рамки ЕСКд на 2А
    [SST.SchDoc]
2024-03-29 Переместил землю так, чтобы её УГОшка была направлена вниз
    [SST.SchDoc]
2024-03-29 Удалил надпись GND с земли
    [SST.SchDoc]
2024-03-29 Поменял обозначения питания
    [SST.SchDoc]
2024-04-21 Started adding titles to MCU pins
    [SST.SchDoc, SST_Schlib.SchLib]
2024-04-24 Created kicad project
    [sst.kicad_pcb, sst.kicad_sch]
2024-04-24 Добавил рамки по госту
    [sst.kicad_sch]
2024-04-25 Switched to gost font and set to metric
    [sst.kicad_pcb]
2024-04-25 Добавил в свою библиотеку из встроенной символ атмеги
2024-04-26 Сделал УГО микроконтроллера по ГОСТ
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2024-04-27 Вроде как полная схемная библиотека
2024-04-28 Almsost done with the sceme: part that connected to MCU is connected
    [sst.kicad_sch]
2024-04-28 Done with schematic
    [sst.kicad_sch]
2024-04-28 Fixes to the schematics
    [sst.kicad_sch]
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2024-04-29 Сделлал аннотацию схемы
    [sst.kicad_sch]
2024-04-29 Linked footprints to schematics
    [sst.kicad_sch]
2024-04-29 Fixes transistor
    [sst.kicad_pcb, sst.kicad_sch]
2024-04-30 Changed couple of footprints for XS
    [sst.kicad_sch]
2024-05-01 first try at tracing, and I think I set wrong component at XS4
    [sst.kicad_pcb]
2024-05-01 Changed footprint for XS4
    [sst.kicad_sch]
2024-05-01 version of PCB layout without errors
    [sst.kicad_pcb]
2024-05-01 pcb without warnings
    [sst.kicad_pcb]
2024-05-02 deleted all tracks
    [sst.kicad_pcb]
2024-05-02 created groups of objects
    [sst.kicad_pcb]
2024-05-02 fixes to potentiometers on schematics
    [sst.kicad_sch]
2024-05-02 Updated pcb according to schematics
    [sst.kicad_pcb]
2024-05-02 Changed capacitors
    [sst.kicad_sch]
2024-05-02 Arranged components on PCB
    [sst.kicad_pcb]
2024-05-02 Rearranged components a little bit
    [sst.kicad_pcb]
2024-05-03 Подписал рамки
    [sst.kicad_sch]
2024-05-03 Traced everything but power
    [sst.kicad_pcb]
2024-05-04 traced pcb
    [sst.kicad_pcb]
2024-05-04 Potentiometer step model
    [P0915N-FC15AR50K.stp]
2024-05-04 placed potentiometers step models
    [sst.kicad_pcb]
2024-05-04 BarellJack step model
    [RAPC10U.step]
2024-05-04 Added barell jack step model
    [sst.kicad_pcb]
2024-05-04 Exported step file of the first board
2024-05-04 Locked elements that would be constant on PCB
    [sst.kicad_pcb]
2024-05-04 PCB with resistors, capacitors and barell jack turned to other side
    [sst_v2.kicad_pcb]
2024-05-04 Вторая компоновка печатной платы в формате step
2024-05-05 Третья версия компоновки ПП с уменьшенными компонентами
    [sst_v3.kicad_pcb]
2024-05-05 Exported step file of the third board
2024-05-06 Removed step downloaded step files
    [P0915N-FC15AR50K.stp, RAPC10U.step]
2024-05-06 Removed some 3d models from first board
    [sst.kicad_pcb]
2024-05-06 Removed step bad 3d models of boards
2024-05-06 Removed some 3d models from second board
    [sst_v2.kicad_pcb]
2024-05-06 Removed some 3d models from third board
    [sst_v3.kicad_pcb]
2024-05-06 Exported step models of PCB's
    [sst.step, sst_v2.step, sst_v3.step]
2024-05-06 Another try to export step models of PCB's
    [sst.step, sst_v2.step, sst_v3.step]
2024-05-08 pcb-s imported in altium
    [sst.PcbDoc, sst_v2.PcbDoc, sst_v3.PcbDoc]
2024-05-08 Imported in Altium kicad sst project
    [sst.PrjPcb]
2024-05-08 kicad .kicad_pcb -> Altium .PcbDoc -> IDF export of the boards
    [sst.brd, sst_v2.brd, sst_v3.brd]
2024-05-13 STEP models from SOLIDWORKS
    [sst.STEP, sst_v2.STEP, sst_v3.STEP]
2024-05-13 STEP models from SOLIDWORKS redone
    [sst.STEP, sst_v2.STEP, sst_v3.STEP]
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
